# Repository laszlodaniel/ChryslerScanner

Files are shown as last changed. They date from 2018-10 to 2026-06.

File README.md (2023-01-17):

# ChryslerScanner [][License] [][Tindie]

Preview

GUI CCD 01

GUI SCI 01

GUI EngineTools 01

GUI BootstrapTools 01

<!----------------------------------------------------------------------------->

[Badge License]: https://img.shields.io/badge/License-GPLv3-blue.svg?style=for-the-badge
[Badge Tindie]: https://img.shields.io/badge/Buy_On_Tindie-17aeb9?style=for-the-badge&logo=shopify&logoColor=white
[Preview]: https://chryslerccdsci.files.wordpress.com/2022/06/img_20220627_101911_02.jpg
[GUI CCD 01]: https://chryslerccdsci.files.wordpress.com/2023/01/chryslerscanner_gui_ccd_01.png
[GUI SCI 01]: https://chryslerccdsci.files.wordpress.com/2023/01/chryslerscanner_gui_sci_01.png
[GUI EngineTools 01]: https://chryslerccdsci.files.wordpress.com/2023/01/chryslerscanner_gui_enginetools_01.png
[GUI BootstrapTools 01]: https://chryslerccdsci.files.wordpress.com/2023/01/chryslerscanner_gui_bootstraptools_01.png
[Tindie]: https://www.tindie.com/products/27210/
[License]: LICENSE

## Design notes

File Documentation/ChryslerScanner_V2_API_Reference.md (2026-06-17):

# Chrysler Scanner V2 API Reference

> **Last Updated:** June 5, 2026  

## 1. Overview
The Chrysler Scanner firmware acts as a high-speed bridge between modern host applications (Windows, macOS, Android, iOS) and legacy Chrysler automotive networks (CCD, PCI, and SCI). 

Communication with the scanner is purely asynchronous, packet-based, and identical across both USB and Bluetooth LE (BLE) transport layers. The scanner operates in a Master/Slave relationship with the host application: the host issues requests or commands, and the scanner responds. The scanner will also independently push asynchronous events (like incoming automotive bus messages) to the host.

## 2. Transport Layers

### 2.1 USB (Serial Port)
* **Baud Rate:** `250000` bps (Default, configurable via API)
* **Data Bits:** 8
* **Parity:** None
* **Stop Bits:** 1
* **Flow Control:** None

### 2.2 Bluetooth Low Energy (BLE)
The scanner implements the standard **Nordic UART Service (NUS)** to emulate a serial stream over BLE.
* **Service UUID:** `6E400001-B5A3-F393-E0A9-E50E24DCCA9E`
* **RX Characteristic (Host -> Scanner):** `6E400002-B5A3-F393-E0A9-E50E24DCCA9E` (Write / Write Without Response)
* **TX Characteristic (Scanner -> Host):** `6E400003-B5A3-F393-E0A9-E50E24DCCA9E` (Notify)

*Note: BLE MTU size negotiation is supported and highly recommended to maximize throughput.*

---

## 3. Packet Framing Protocol
Every byte of data exchanged between the host and the scanner is wrapped in a strict packet frame. The framing protocol ensures data integrity, synchronizes streams, and explicitly routes payloads.

### 3.1 Packet Structure

| Byte Offset | Field Name | Size | Type | Description |
| :--- | :--- | :--- | :--- | :--- |
| `0` | **Sync** | 1 byte | `uint8` | Always `0x3D` (`=`). Used to synchronize the stream. |
| `1 - 2` | **Length** | 2 bytes | `uint16` | Total length of the Payload + 2 (Big Endian). |
| `3` | **Routing** | 1 byte | `uint8` | Bitmapped field containing Direction, Bus ID, and Command. |
| `4` | **Mode** | 1 byte | `uint8` | Sub-command modifier (varies by Command). |
| `5` to `N-2` | **Payload** | `N` bytes | `uint8[]`| Optional data. Length = `Length field - 2`. |
| `N-1` | **Checksum** | 1 byte | `uint8` | 8-bit additive sum of all preceding bytes. |

**Total Packet Size Calculation:**  
`Total Size = Payload Length + 6 bytes`

### 3.2 The Routing Byte (Byte 3)
The routing byte is a bitmapped flag that determines where the packet came from, what subsystem it targets, and what action to perform.

| Bit 7 (MSB) | Bit 6-4 | Bit 3-0 (LSB) |
| :---: | :---: | :---: |
| **Direction** | **Bus ID** | **Command ID** |

* **Direction Bit:** 
  * `0` = Host to Scanner (Requests)
  * `1` = Scanner to Host (Responses)
* **Bus ID (Bits 6-4):**
  * `0x0` = USB / Internal System
  * `0x1` = CCD Bus
  * `0x2` = SCI Bus (PCM / Engine)
  * `0x3` = SCI Bus (TCM / Transmission)
  * `0x4` = PCI Bus
* **Command ID (Bits 3-0):**
  * `0x0` = Reset
  * `0x1` = Handshake
  * `0x2` = Status
  * `0x3` = Settings
  * `0x4` = Request
  * `0x5` = Response
  * `0x6` = Message TX (Send to Car)
  * `0x7` = Message RX (Received from Car)
  * `0xC` = File Operations
  * `0xD` = Bootloader / ECU Flashing
  * `0xE` = Debug / Emulator
  * `0xF` = Error

### 3.3 Checksum Calculation
The checksum is a simple 8-bit unsigned rollover sum of all bytes in the packet *excluding* the checksum byte itself.

**C# / C++ Example:**
```csharp
public byte CalculateChecksum(byte[] buffer, int lengthWithoutChecksum)
{
    byte checksum = 0;
    for (int i = 0; i < lengthWithoutChecksum; i++)
    {
        checksum += buffer[i]; // Rollover is intentional
    }
    return checksum;
}
```

---

## 4. Packet Construction Example

**Scenario:** Host wants to request the scanner's Hardware/Firmware Info.
* `Sync`: `0x3D`
* `Length`: `0x0002` (0 Payload bytes + 2)
* `Routing`: `0x04` (Direction=0, Bus=USB[0], Cmd=Request[4])
* `Mode`: `0x01` (Req_HwFw_Info)
* `Payload`: [None]

**Raw Host TX:** `3D 00 02 04 01 44` *(0x44 is the sum of 3D+00+02+04+01)*

**Scanner Response:**
* `Sync`: `0x3D`
* `Length`: `0x0019` (23 Payload bytes + 2)
* `Routing`: `0x85` (Direction=1, Bus=USB[0], Cmd=Response[5])
* `Mode`: `0x01` (Res_HwFw_Info)
* `Payload`: `[23 bytes of Hardware/Firmware Data]`

---

## 5. Global Error Responses
If the host sends an invalid packet or the scanner encounters an internal error, it will respond with an **Error Packet**.

**Routing Byte:** `0x8F` (Scanner to Host, USB Bus, Error Command)
**Payload:** Usually a single `0xFF` byte, though it can be ignored.
**Mode Byte (The Error Code):**
* `0x00` = OK (Acknowledge)
* `0x01` = Length Invalid Value
* `0x02` = Invalid Command (Command ID not recognized)
* `0x03` = Invalid Mode (Mode/Sub-command not recognized)
* `0x04` = Invalid Payload Values
* `0x05` = Checksum Invalid
* `0x06` = Packet Timeout (RX stream stalled)
* `0x07` = Buffer Overflow
* `0x08` = Invalid Bus
* `0xFE` = Internal Execution Error
* `0xFF` = Fatal Error

*Example of a standard "OK" ACK from the scanner (Length=3, Payload=[0x00]):*  
`3D 00 03 8F 00 00 CF`

---

# 6. Core System Commands

These commands handle the fundamental lifecycle and identification of the scanner.

### 6.1 Reset Scanner (`Command ID: 0x00`)
Reboots the ESP32 microcontroller or notifies the host that a reboot has occurred.

*   **Host Request Mode:** `0x00` (`rm_init`)
    *   **Payload:** 1 byte (Reset reason requested by host, user-defined)
*   **Scanner Response Mode:** `0x01` (`rm_done`)
    *   **Payload:** 1 byte (Actual hardware reset reason, via `esp_reset_reason()`)
    *   *Note: The scanner broadcasts this automatically upon startup.*

### 6.2 Handshake (`Command ID: 0x01`)
Used to identify the device and verify communication channels are active.

*   **Host Request Mode:** `0x00` (`hm_none`)
    *   **Payload:** None
*   **Scanner Response Mode:** `0x00`
    *   **Payload:** 15 bytes (ASCII String: `CHRYSLERSCANNER`)

### 6.3 Status (`Command ID: 0x02`)
Retrieves a comprehensive real-time snapshot of the scanner's internal state, memory, voltages, and bus statistics.

*   **Host Request Mode:** `0x00` (`sm_none`)
    *   **Payload:** None
*   **Scanner Response Mode:** `0x00`
    *   **Payload:** 45 bytes (All multi-byte integers are **Big-Endian**)

| Byte Offset | Type | Description |
| :--- | :--- | :--- |
| `0 - 3` | `uint32` | Device Uptime in milliseconds |
| `4 - 7` | `uint32` | RAM Usage (Total Heap - Free Heap) in bytes |
| `8 - 9` | `uint16` | Battery Voltage (mV) |
| `10 - 11` | `uint16` | Bootstrap Voltage / VBB (mV) |
| `12 - 13` | `uint16` | Programming Voltage / VPP (mV) |
| `14` | `uint8` | Current CCD-Bus Settings Byte |
| `15 - 18` | `uint32` | CCD-Bus RX Packet Count |
| `19 - 22` | `uint32` | CCD-Bus TX Packet Count |
| `23` | `uint8` | Current PCI-Bus Settings Byte |
| `24 - 27` | `uint32` | PCI-Bus RX Packet Count |
| `28 - 31` | `uint32` | PCI-Bus TX Packet Count |
| `32` | `uint8` | Current SCI-Bus Settings Byte |
| `33 - 36` | `uint32` | SCI-Bus RX Packet Count |
| `37 - 40` | `uint32` | SCI-Bus TX Packet Count |
| `41 - 42` | `uint16` | LED Heartbeat Interval (ms) |
| `43 - 44` | `uint16` | LED Blink Duration (ms) |

---

# 7. Device Settings (`Command ID: 0x03`)
Settings commands configure hardware peripherals. The scanner automatically saves these parameters to Non-Volatile Storage (NVS) and acknowledges by echoing the packet back (`Direction` bit set to `1`).

### 7.1 Set LED Mode (`Mode: 0x01`)
Configures the device's status LEDs.
*   **Payload:** 4 bytes
    *   Bytes 0-1: Heartbeat Interval (ms) (`0` = disable heartbeat)
    *   Bytes 2-3: Blink Duration (ms) (`0` = completely disable LEDs)

### 7.2 Set CCD-Bus Configuration (`Mode: 0x02`)
*   **Payload:** 1 byte (Bit 7: `1` = Enable Bus, `0` = Disable Bus)

### 7.3 Set PCI-Bus Configuration (`Mode: 0x06`)
*   **Payload:** 1 byte (Bit 7: `1` = Enable Bus, `0` = Disable Bus)

### 7.4 Set SCI-Bus Configuration (`Mode: 0x03`)
SCI setup requires strict multiplexing of the `AW9523` port expander and UART logic levels.
*   **Payload:** 1 byte (Bitmapped)

| Bit(s) | Function | Description |
| :---: | :--- | :--- |
| `7` | **Enable** | `1` = Enable transceiver, `0` = Disable |
| `6` | **Nibble Swap** | `1` = Swap 4-bit nibbles in received/transmitted bytes |
| `5` | **Module Target** | `0` = PCM (Engine), `1` = TCM (Transmission) |
| `4` | **NGC Mode** | `1` = Next Generation Controller, `0` = Legacy (SBEC/JTEC/EATX) |
| `3` | **Logic Polarity** | `1` = Inverted / OBD1, `0` = Normal / OBD2 |
| `2` | **OBD Config** | Pin routing switch. `0` = Config A, `1` = Config B |
| `1 - 0` | **Baudrate** | `0` = 976, `1` = 7812, `2` = 62500, `3` = 125000 bps |

### 7.5 Apply SCI VXX Strobe Voltage (`Mode: 0x07`)
Activates hardware level-shifters to apply high voltage directly to the active SCI-TX pin. Crucial for flashing or unlocking bootstrap modes.
*   **Payload:** 2 bytes (`uint16`, Big-Endian) in millivolts.
    *   `0x0000` (0) = `VXX_NONE` (Off)
    *   `0x2EE0` (12000) = `VBB` (Bootstrap Voltage)
    *   `0x4E20` (20000) = `VPP` (Programming Voltage)

### 7.6 Set USB UART Baudrate (`Mode: 0x08`)
Changes the baud rate of the primary USB Serial connection.
*   **Payload:** 4 bytes (`uint32`, Big-Endian). *Default is 250,000.*

---

# 8. System Requests (`Command ID: 0x04`)
Requests prompt the scanner to return specific diagnostic information. The scanner responds with `Command ID: 0x05`.

| Request Mode (`0x04`) | Response Mode (`0x05`) | Payload Description (Response) |
| :--- | :--- | :--- |
| `0x01` (HW/FW Info) | `0x01` | **23 Bytes:** HW Ver (4 bytes, nibble-split), FW Major, Minor, Build, Rev (4 bytes), Chip Model (1 byte), Chip Rev (2 bytes), Cores (1 byte), Features (4 bytes), Flash Size in MB (1 byte), Bluetooth MAC Address (6 bytes). |
| `0x02` (Timestamp) | `0x02` | **4 Bytes:** `uint32` Milliseconds since boot. |
| `0x03` (Battery Volts) | `0x03` | **2 Bytes:** `uint16` Voltage in mV. |
| `0x06` (VBB Volts) | `0x06` | **2 Bytes:** `uint16` 12V Bootstrap output in mV. |
| `0x07` (VPP Volts) | `0x07` | **2 Bytes:** `uint16` 20V Programming output in mV. |
| `0x08` (All Voltages) | `0x08` | **6 Bytes:** Batt, VBB, VPP (`uint16` x 3). |

---

# 9. Debug & OTA Updates (`Command ID: 0x0E`)
These sub-commands interact with the ESP32's deeper system functions, including Over-The-Air firmware updates and the internal hardware SCI emulator.

### 9.1 SCI Emulator Commands
The scanner can physically simulate a Chrysler PCM/TCM on the SCI bus for software testing without a real vehicle.
*   **Enable/Disable Emulator (`Mode: 0x0B`):** 
    *   Payload: `0x01` (Enable), `0x00` (Disable)
*   **Set Emulator OBD1 Mode (`Mode: 0x0D`):**
    *   Payload: `0x01` (OBD1 Logic), `0x00` (OBD2 Logic)
*   **Set Emulator ECM Mode (`Mode: 0x0E`):**
    *   Payload: `0x01` (Cummins Diesel Engine Controller), `0x00` (Normal Engine Controller)
*   **Upload Emulator Data Blob (`Mode: 0x0C`):**
    *   Payload: Up to 1024 bytes. This binary blob defines the simulated diagnostic fault codes, ROM IDs, and sensor responses. The scanner stores this blob in NVS. Blob format is not public yet.

### 9.2 Over-The-Air (OTA) Firmware Updates
Allows 3rd-party apps to flash new ESP32 firmware updates directly to the scanner over USB or BLE.

1.  **Start OTA (`Mode: 0x15`):** Payload: None. Opens the inactive OTA partition.
2.  **Set Hash (`Mode: 0x17`):** Payload: 32 bytes (SHA-256 Hash of the `.bin` file). *Highly recommended to verify integrity.*
3.  **Write Chunk (`Mode: 0x18`):** Payload: Variable length data chunk. Send sequentially until the `.bin` file is fully transferred.
4.  **Finalize OTA (`Mode: 0x19`):** Payload: None. Verifies the SHA-256 hash against the written partition, sets the boot flag, and automatically reboots the scanner.
5.  **Abort OTA (`Mode: 0x16`):** Payload: None. Cancels an active OTA and cleans up.
6.  **Revert Firmware (`Mode: 0x1A`):** Payload: None. Rolls the scanner back to the previously installed firmware version and reboots.

### 9.3 System Debug
*   **Get Task Stack Statistics (`Mode: 0x20`):** Payload: None. Prints FreeRTOS High-Water Marks to the debug UART to check for memory leaks.
*   **Set BLE MTU Size (`Mode: 0x30`):** 
    *   Payload: 2 bytes (`uint16` Big-Endian). Requests a larger Maximum Transmission Unit for BLE before connection to maximize Bluetooth bandwidth.

---

# 10. Automotive Bus Messaging

The scanner allows raw data injection and extraction from the vehicle's CCD, PCI, and SCI networks. 

*   **Host to Scanner (Transmit):** Command ID `0x06` (`cmd_msg_tx`)
*   **Scanner to Host (Receive):** Command ID `0x07` (`cmd_msg_rx`)

### 10.1 Receiving Messages from the Vehicle
When the scanner receives a valid message on an active bus, it wraps it in an `0x07` packet and pushes it asynchronously to the host.

**Response Mode Byte:**
*   `0x01`: CCD, PCI, or SCI Low-Speed message.
*   `0x02`: SCI High-Speed message (Multiplexed/Streamed/Bootstrap).

**Payload Structure (RX):**
| Byte Offset | Type | Description |
| :--- | :--- | :--- |
| `0 - 3` | `uint32` | **Timestamp:** Milliseconds since the scanner booted (Big-Endian). Extremely useful for Host-side charting/logging. |
| `4 - N` | `uint8[]` | **Raw Bus Message:** The actual bytes captured from the vehicle network (including checksums/CRCs if applicable). |

### 10.2 Transmitting Messages to the Vehicle
When transmitting, the host specifies *how* the scanner should push the data using the **Mode** byte.

*   `0x01` (**Stop**): Stops any active repeating transmission loops. (Payload: None)
*   `0x02` (**Single**): Transmits the payload once.
*   `0x03` (**List**): Transmits a sequence of different messages sequentially.
*   `0x04` (**Repeat**): Transmits a message (or sequence) infinitely at a strict hardware-timed interval.
*   `0x81` (**Single + VBB**): *[SCI Bus Only]* Transmits the payload once, then immediately applies 12V Bootstrap Voltage to the SCI-TX pin (used for waking up PCMs in Bootstrap mode).
*   `0x82` (**Single + VPP**): *[SCI Bus Only]* Transmits the payload once, then immediately applies 20V Programming Voltage to the SCI-TX pin (used for unlocking Flash memory).

**Payload Structure (Single TX `0x02`, `0x81`, `0x82`):**
Simply append the raw bytes. 
*Note: For CCD, the scanner hardware automatically calculates and appends the 8-bit checksum. For PCI, it calculates and appends the J1850 CRC. For SCI (Legacy), the host must provide the exact bytes. For SCI (NGC), the scanner appends the checksum automatically.*

**Payload Structure (Repeat / List TX `0x03`, `0x04`):**
| Byte Offset | Type | Description |
| :--- | :--- | :--- |
| `0 - 1` | `uint16` | **Interval:** Delay in milliseconds between transmissions. |
| `2` | `uint8` | **Length (L1):** Length of the first message. |
| `3 - (3+L1-1)` | `uint8[]` | **Message 1 Data** |
| `3+L1` | `uint8` | **Length (L2):** Length of the second message (optional). |
| `...` | `...` | ... repeats up to 1024 bytes of buffer space. |

---

# 11. Internal Storage (LittleFS)
The scanner uses an internal Flash partition (LittleFS) to store firmware for backup dumps or files intended for writing. Command ID: `0x0C`.

| Mode (`0x0C`) | Action | Host Payload | Scanner Response Payload |
| :--- | :--- | :--- | :--- |
| `0x01` | **Storage Info** | None | `Total Bytes` (uint32), `Used Bytes` (uint32), followed by a concatenated list of files (see 11.1). |
| `0x02` | **File Info** | Null-terminated string (Filename) | `Filename` (\0), `Exists` (uint8, 1=true), `Size` (uint32). |
| `0x03` | **Upload File** | `Filename` (\0), followed by raw byte chunk. | Standard ACK (`0x00`) or Error (`0xFF`). |
| `0x04` | **Download File** | `Filename` (\0), `Block Size` (uint16). | Scanner starts pushing chunks to host via Mode `0x04`. |
| `0x05` | **Rename File** | `Old Name` (\0), `New Name` (\0), `Overwrite` (uint8 boolean). | Standard ACK or Error. |
| `0x06` | **Delete File** | Null-terminated string (Filename). | Standard ACK or Error. |
| `0x07` | **Format** | None. (Wipes the entire LittleFS partition). | Standard ACK or Error. |
| `0x08` | **Cancel DL** | None. Stops an active `0x04` download stream. | Standard ACK. |
| `0x10` | **Read Chunk** | `Filename` (\0), `Offset` (uint32), `Length` (uint32). | Scanner returns the exact byte chunk requested. |

### 11.1 Storage Info File List Format
When requesting Storage Info (`0x01`), the file list appended to the payload is structured as follows:
`[Total Files (uint8)] [Record Length (uint8)] [Filename (\0)] [Size (uint32)] ...`
*Example: `01 12 74 65 73 74 2E 62 69 6E 00 00 00 00 80` -> 1 File, 18 bytes record length, "test.bin", 128 bytes size.*

---

# 12. ECU Bootloader & Flashing (Autoboot)
Flashing vintage engine controllers requires microsecond-perfect timing to inject bootstrap code into the target MCU's RAM. Because USB/BLE latency is unpredictable, the **ESP32 handles the entire state machine natively**. The Host app simply configures the job and monitors progress.

Command ID: `0x0D` (`cmd_boot`)

### 12.1 Target ECU Loaders (Byte 0)
*   `0x01` = SBEC2
*   `0x02` = SBEC3 / SBEC3+
*   `0x03` = SBEC3A / SBEC3A+ / SBEC3B
*   `0x04` = EATX3 / EATX3A (Transmission)
*   `0x05` = EATX3B (Transmission)
*   `0x06` = EATX4 (Transmission)
*   `0x07` = JTEC
*   `0x08` = JTEC+

### 12.2 Operation Modes
The Host sends an `0x0D` packet with one of the following **Modes**:

#### Automated State Machines
*   `0x01` (`bm_flash_write`): Full Flash Write cycle (Unlock, Erase, Write, Verify).
*   `0x02` (`bm_flash_read`): Full Flash Backup cycle (Unlock, Read to LittleFS).
*   `0x03` (`bm_eeprom_write`): EEPROM Write cycle.
*   `0x04` (`bm_eeprom_read`): EEPROM Read cycle.
*   `0x0A` (`bm_read_68hc11`): Read Co-Processor memory.

**Host Payload for Automated Modes:**
| Byte | Description |
| :--- | :--- |
| `0` | **Loader ID** (e.g., `0x01` for SBEC2) |
| `1` | **Flags (Bitmapped)**<br>Bit 0: Backup original to LittleFS before writing (`1` = yes)<br>Bit 1: Is 64K Chip? (`1` = 64K, `0` = 32K, SBEC2 only)<br>Bit 2: Is Jeep variant? (`1` = Jeep, SBEC2 only)<br>Bit 3: Deep Erase (`1` = Force full wipe) |
| `2 - N` | **Null-Terminated String:** Filename in LittleFS to Read from. |

#### State Machine Control
*   `0x09` (`bm_cancellation_request`): Safely aborts an active Autoboot sequence. (Payload: None)
*   `0x0B` (`bm_boot_next_task_request`): Acknowledges a host prompt. *(Note: SBEC2 controllers must be power-cycled during the write sequence. The ESP32 will pause the state machine and wait for the Host to send `0x0B` after the user cycles the ignition key).*

### 12.3 Status Notifications
While the Autoboot sequence runs, the scanner pushes continuous status updates to the Host (Direction = `1`, Command = `0x0D`). 

The **Payload** of these status updates contains a 1-byte Status Code, optionally followed by data.

**Success / Progression Codes:**
*   `0x00`: Job Complete Successfully.
*   `128`: Verifying Voltages...
*   `129`: Voltages OK.
*   `132`: Part Number Extracted. (Payload: ASCII String of Part Number).
*   `133`: Backup Created. (Payload: ASCII String of generated backup filename).
*   `136`: Flash IDs Extracted. (Payload: 2 bytes `[Manufacturer ID] [Chip ID]`).
*   `142`: Flash Erase Result. (Payload: 1 byte response from worker, `0x22` is success).
*   `168`: Re-uploading Bootloader (Prompting user for Ignition Cycle).

**Error Codes (Causes immediate sequence halt):**
*   `01`: Flash File Missing in LittleFS.
*   `02`: Flash File Size Mismatch.
*   `03`: Storage Full (Cannot create backup).
*   `05`: Battery Voltage Low (< 11.5V).
*   `06`: Bootstrap Voltage VBB Low (< 11.5V).
*   `07`: Programming Voltage VPP Low (< 19.0V).
*   `12`: Flash Checksum Mismatch (Write verification failed).
*   `18`: Upload Worker Timeout.
*   `19`: Start Worker Timeout.
*   `22`: Task Cancelled by Host.

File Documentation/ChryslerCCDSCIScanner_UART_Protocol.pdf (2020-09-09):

Chrysler CCD/SCI Scanner V1.4X | UART Protocol

## Chrysler CCD/SCI Scanner UART Protocol

V1.4X

Last update: 2020.09.09

## 1. Frame format

Start of frame | Frame length | Frame description | Data | End of frame
SYNC | LENGTH HB | LENGTH LB | DATA CODE | SUB-DATA CODE | PAYLOAD | CHECKSUM
3D | 00 | 06 | 05 | 02 | 00 DA A9 0D | 9D

Table 1. Frame format example (hex numbers implied).

SYNC byte: fixed value at the beginning of every frame (3D).

LENGTH bytes: number of bytes following (not including these two) until the CHECKSUM byte is reached. Maximum frame length is limited to 1024 bytes.
Size: 2 bytes.

DATA CODE byte: describes the source, target and command. Size: 1 byte.

SUB-DATA CODE byte: command extension if the command alone is not enough to describe the purpose of the frame. Size: 1 byte

PAYLOAD byte(s): optional. Arbitrary data can be stored here. Size: limited to a maximum of 1024-6=1018 bytes.

CHECKSUM byte: all bytes, except SYNC, summed up, lower byte of the result is placed here for error detection. Size: 1 byte.

Frame transmission and reception is realized via +5V logic serial communication with non-return-to-zero (NRZ) encoding at 250000 baudrate either trough the USB or FTDI connector.

## 2. Frame bytes in detail

### 2.1 DATA CODE byte description

DATA CODE byte
Source | Target | Command
bit 7 | bit 6 | bit 5 | bit 4 | bit 3 | bit 2 | bit 1 | bit 0
0 | 0 | 1 | 0 | 0 | 1 | 1 | 0
Table 2. DATA CODE byte description.

Bit 7:6 – Source of the frame: 00b: USB
01b: CCD
10b: PCM
11b: TCM

Bit 5:4 – Target of the frame: 00b: USB
01b: CCD
10b: PCM
11b: TCM

USB: the scanner/laptop itself.
CCD: all modules on CCD-bus.
PCM: engine controller on SCI-bus.
TCM: transmission controller on a separate SCI-bus. This channel is currently unused. TCMs mainly communicate on the CCD-bus and can be reached there for diagnostics purposes.

Bit 3:0 – Command
0000b (00): Reset
0001b (01): Handshake
0010b (02): Status
0011b (03): Settings
0100b (04): Request
0101b (05): Response
0110b (06): Message TX
0111b (07): Message RX
1000b-1101b (08-0D): reserved
1110b (0E): Debug
1111b (0F): OK/Error

### 2.2 SUB-DATA CODE byte description

Individual bits have no special meaning. Different commands have different SUB-DATA CODE bytes associated with them. When not used it always reads 00, otherwise this value extends the meaning of the DATA CODE byte.

## 3. Frame examples

### 3.1 Reset (command: 00)

Applicable SUB-DATA CODE bytes (modes): 00: initiate scanner reset.
01: scanner reset done.
02-FF: reserved.
SYNC | LENGTH HB | LENGTH LB | DATA CODE | SUB-DATA CODE | PAYLOAD | CHECKSUM
3D | 00 | 02 | 00 | 00 | | 02

Table 3. Reset scanner request frame.

SYNC | LENGTH HB | LENGTH LB | DATA CODE | SUB-DATA CODE | PAYLOAD | CHECKSUM
3D | 00 | 03 | 00 | 00 | 00 | 03

Table 4. Scanner is being reset frame.

SYNC | LENGTH HB | LENGTH LB | DATA CODE | SUB-DATA CODE | PAYLOAD | CHECKSUM
3D | 00 | 03 | 00 | 01 | 00 | 04

Table 5. Scanner reset complete frame.

Note that the scanner never sends a communication packet without payload but accepts them without one. In a response made by the scanner at least a single 00 byte is included and it generally means success.

### 3.2 Handshake (command: 01)

Applicable SUB-DATA CODE bytes (modes):
00: request handshake only.
01: request handshake, hardware/firmware information and scanner status. 02-FF: reserved.
SYNC | LENGTH HB | LENGTH LB | DATA CODE | SUB-DATA CODE | PAYLOAD | CHECKSUM
3D | 00 | 02 | 01 | 00 | | 03

Table 6. Handshake request frame.

SYNC | LENGTH HB | LENGTH LB | DATA CODE | SUB-DATA CODE | PAYLOAD | CHECKSUM
3D | 00 | 02 | 01 | 01 | | 04

Table 7. Handshake request frame with additional information.

SYNC | LENGTH HB | LENGTH LB | DATA CODE | SUB-DATA CODE | PAYLOAD | CHECKSUM
3D | 00 | 17 | 01 | 00 | 43 48 52 59 53 4C 45 52 43 43 44 53 43 49 53 43 41 4E 4E 45 52 | 37

Table 8. Handshake response frame.

PAYLOAD contains an ASCII encoded text:
43 48 52 59 53 4C 45 52 43 43 44 53 43 49 53 43 41 4E 4E 45 52 = CHRYSLERCCDSCISCANNER

A third party software should look for a response like this when searching for the scanner among many serial devices.

Another 2 separate frames are sent by the scanner when additional information is requested: 1 hardware/firmware version and 1 status frame.

### 3.3 Status (command: 02)

No sub-data code byte/mode is applicable here, reads always 00.

SYNC | LENGTH HB | LENGTH LB | DATA CODE | SUB-DATA CODE | PAYLOAD | CHECKSUM
3D | 00 | 02 | 02 | 00 | | 04

Table 9. Status request frame.

SYNC | LENGTH HB | LENGTH LB | DATA CODE | SUB-DATA CODE | PAYLOAD | CHECKSUM
3D | 00 | 2E | 02 | 00 | 1E 98 01 01 31 31 00 1E AC AE 0B B2 00 00 00 51 00 00 00 00 00 00 00 00 91 00 00 00 0C 00 00 00 0C 01 27 14 04 14 01 02 13 88 00 32 | 9D

Table 10. Status response frame.

PAYLOAD offset:
00-02: AVR signature (1E 98 01 for ATmega2560).
03: | external EEPROM present (00: false, 01: true).
04: | external EEPROM checksum.
05: | external EEPROM calculated checksum.
06-09: current timestamp in milliseconds.
0A-0B: RAM usage out of 8192 bytes.
0C: connected to vehicle (00: false, 01: true).
0D-0E: measured vehicle battery voltage (multiplied by 100).
0F: | CCD-bus status byte:
| Bit 7:6 – bus id bits, reads 01b for CCD-bus.
| Bit 5: – change settings bit, reads always 0b (0b: keep, 1b: change).
| Bit 4: – state bit (0b: disabled, 1b: enabled).
| Bit 3: – logic bit, reads always 0b (0b: non-inverted, 1b: inverted).
| Bit 2: – termination and bias (TB) bit (0b: disabled, 1b: enabled).
| Bit 1:0 – baudrate bits (00b: 976.5, 01b: 7812.5, 10b: 62500, 11b:
| 125000), reads always 01b as the only known communication
| speed for CCD-bus.
10-13: number of CCD-bus messages received. 14-17: number of CCD-bus messages sent.
18: | SCI-bus (PCM) status byte:
| Bit 7:6 – bus id bits, reads 10b for the PCM.
| Bit 5: – change settings bit (0b: keep settings, 1b: change settings).
| Bit 4: – state bit (0b: disabled, 1b: enabled).
| Bit 3: – logic bit (0b: non-inverted, 1b: inverted).
| Bit 2: – OBD configuration bit (0b: A, 1b: B).
| Bit 1:0 – baudrate bits (00b: 976.5, 01b: 7812.5, 10b: 62500, 11b:
| 125000), 7812.5 and 62500 baud are most commonly used.
19-1C: number of SCI-bus (PCM) messages received. 1D-20: number of SCI-bus (PCM) messages sent.
21: | LCD state (00: disabled, 01: enabled).
22: | LCD I2C address.
23: | LCD width in characters.
24: | LCD height in characters.
25: | LCD refresh rate in Hz.
26: | LCD units (00: imperial, 01: metric).
27: | LCD data source (01: CCD-bus, 02: SCI-bus PCM, 03: SCI-bus TCM).
28-29: LED heartbeat interval in milliseconds.
2A-2B: LED blink duration in milliseconds.

### 3.4 Settings (command: 03)

Applicable SUB-DATA CODE bytes (modes): 01: heartbeat / LED behavior.
02: set CCD-bus.
03: set SCI-bus.
04: set repeat behavior.
05: set LCD.
00,06-FF: reserved.

### 3.4.1 Heartbeat / LED behavior mode

SYNC | LENGTH HB | LENGTH LB | DATA CODE | SUB-DATA CODE | PAYLOAD | CHECKSUM
3D | 00 | 06 | 03 | 01 | 13 88 00 32 | D7

Table 11. Change heartbeat / LED behavior setting frame.

PAYLOAD offset:
00-01: heartbeat interval in milliseconds, 5000 ms = 13 88. 02-03: blink duration for all LEDs in milliseconds, 50 ms = 00 32.
SYNC | LENGTH HB | LENGTH LB | DATA CODE | SUB-DATA CODE | PAYLOAD | CHECKSUM
3D | 00 | 07 | 03 | 01 | 00 13 88 00 32 | D8

Table 12. Heartbeat / LED behavior setting response frame.

PAYLOAD offset:
00: setting state (00: ok, FF: error). 01-02: heartbeat interval in milliseconds. 03-04: LED blink duration in milliseconds.

### 3.4.2 Set CCD-bus mode

SYNC | LENGTH HB | LENGTH LB | DATA CODE | SUB-DATA CODE | PAYLOAD | CHECKSUM
3D | 00 | 04 | 03 | 02 | 01 00 | 0A

Table 13. Change CCD-bus setting frame.

PAYLOAD offset:
00: CCD-bus state (00: disabled, 01: enabled).
01: internal CCD-bus termination and bias state (00: disabled,
01: enabled). This feature is available for V1.44+ hardware versions only.
SYNC | LENGTH HB | LENGTH LB | DATA CODE | SUB-DATA CODE | PAYLOAD | CHECKSUM
3D | 00 | 05 | 03 | 02 | 00 01 00 | 0B

Table 14. CCD-bus setting response frame.

PAYLOAD offset:
00: setting state (00: ok, FF: error).
01: CCD-bus state.
02: internal CCD-bus termination and bias state.

### 3.4.3 Set SCI-bus mode

SYNC | LENGTH HB | LENGTH LB | DATA CODE | SUB-DATA CODE | PAYLOAD | CHECKSUM
3D | 00 | 03 | 03 | 03 | B1 | BA

Table 15. Change SCI-bus setting frame.

PAYLOAD offset:
00: SCI-bus status:
Bit 7:6 – bus id bits, reads 10b for the PCM (11b for TCM).
Bit 5: – change settings bit (0b: keep settings, 1b: change settings). Bit 4: – state bit (0b: disabled, 1b: enabled).
Bit 3: – logic bit (0b: non-inverted, 1b: inverted).
Bit 2: – OBD configuration bit (0b: A, 1b: B).
Bit 1:0 – baudrate bits (00b: 976.5, 01b: 7812.5, 10b: 62500, 11b: 125000)

Example: B1 = 10110001b
10b: PCM
1b: change settings
1b: enabled state
0b: non-inverted logic
0b: A-configuration
01b: 7812.5 baudrate

The 5th change settings bit must always be set, otherwise the scanner ignores the request.

SYNC | LENGTH HB | LENGTH LB | DATA CODE | SUB-DATA CODE | PAYLOAD | CHECKSUM
3D | 00 | 04 | 03 | 03 | 00 91 | 9B

Table 16. SCI-bus setting response frame.

PAYLOAD offset:
00: setting state (00: ok, FF: error). 01: SCI-bus state.

Example: 91 = 10010001b
10b: PCM
0b: keep settings
1b: enabled state
0b: non-inverted logic
0b: A-configuration
01b: 7812.5 baudrate

The 5th change settings bit is necessarily cleared if it comes as a response.

### 3.4.4 Set repeat behavior mode

SYNC | LENGTH HB | LENGTH LB | DATA CODE | SUB-DATA CODE | PAYLOAD | CHECKSUM
3D | 00 | 07 | 03 | 04 | 01 00 64 00 02 | 75

Table 17. Change repeat behavior setting frame.

PAYLOAD offset:
00: target bus (01: CCD-bus, 02: SCI-bus PCM, 03: SCI-bus TCM).
01-02: message repeat interval in milliseconds, 100 ms = 00 64.
03-04: message increment for every repeat, 2 = 00 02.

When message repeating is enabled the scanner uses the interval set here for message timing. Message incrementing is applicable to a specific B2-request message only.

SYNC | LENGTH HB | LENGTH LB | DATA CODE | SUB-DATA CODE | PAYLOAD | CHECKSUM
3D | 00 | 08 | 03 | 04 | 00 01 00 64 00 02 | 76

Table 18. Repeat behavior setting response frame.

PAYLOAD offset:
00: setting state (00: ok, FF: error).
01: target bus.
02-03: message repeat interval in milliseconds. 04-05: message increment for every repeat.

### 3.4.5 Set LCD mode

SYNC | LENGTH HB | LENGTH LB | DATA CODE | SUB-DATA CODE | PAYLOAD | CHECKSUM
3D | 00 | 09 | 03 | 05 | 01 27 14 04 14 01 02 | 68

Table 19. Change LCD setting frame.

PAYLOAD offset:
00: state (00: disabled, 01: enabled). 01: I2C address, 27 (hex).
02: character width, 14: 20 characters. 03: character height, 04: 4 characters.
04: refresh rate in Hz, 14: 20 Hz.
05: units (00: imperial, 01: metric).
06: data source (01: CCD-bus, 02: SCI-bus PCM, 03: SCI-bus TCM).
SYNC | LENGTH HB | LENGTH LB | DATA CODE | SUB-DATA CODE | PAYLOAD | CHECKSUM
3D | 00 | 0A | 03 | 05 | 00 01 27 14 04 14 01 02 | 69

Table 20. LCD setting response frame.

PAYLOAD offset:
00: setting state (00: ok, FF: error).
01-07: current LCD settings, refer to Table 19’s PAYLOAD offset.

LCD settings are saved to the external EEPROM.

### 3.5 Request/Response (command: 04/05)

Applicable SUB-DATA CODE bytes (modes):
01: hardware/firmware information.
02: timestamp.
03: battery voltage.
04: external EEPROM checksum.
05: CCD-bus voltages.
00,06-FF: reserved.

### 3.5.1 Hardware/Firmware information request mode

SYNC | LENGTH HB | LENGTH LB | DATA CODE | SUB-DATA CODE | PAYLOAD | CHECKSUM
3D | 00 | 02 | 04 | 01 | | 07

Table 21. Hardware/Firmware information request frame.

SYNC | LENGTH HB | LENGTH LB | DATA CODE | SUB-DATA CODE | PAYLOAD | CHECKSUM
3D | 00 | 1C | 05 | 01 | 00 8C 00 00 00 00 5B 7B EA 33 00 00 00 00 5C 02 56 AF 00 01 00 00 5F 19 B9 2A | 60

Table 22. Hardware/Firmware information response frame.

PAYLOAD offset:
00-01: hardware version, 00 8C = 140 -> v1.40. 02-09: hardware date, 00 00 00 00 5B 7B EA 33: 64-bit UNIX time (2018.08.21 12:32:19). 0A-11: assembly date, 00 00 00 00 5C 02 56 AF: 64-bit UNIX time (2018.12.01 10:38:55).
12-09: firmware version/date:
00 01 00 00: major minor patch (build) -> v0.1.0(.0),
5F 19 B9 2A: 32-bit UNIX time (2020.07.23 18:22:02).

### 3.5.2 Timestamp request mode

SYNC | LENGTH HB | LENGTH LB | DATA CODE | SUB-DATA CODE | PAYLOAD | CHECKSUM
3D | 00 | 02 | 04 | 02 | | 08

Table 23. Timestamp request frame.

SYNC | LENGTH HB | LENGTH LB | DATA CODE | SUB-DATA CODE | PAYLOAD | CHECKSUM
3D | 00 | 06 | 05 | 02 | 01 F2 03 23 | 26

Table 24. Timestamp response frame.

PAYLOAD offset:
00-03: milliseconds elapsed since last reset: 01 F2 03 23 = 32637731 ms = 09:03:57.731 (HH:mm:ss.fff).

### 3.5.3 Battery voltage request mode

SYNC | LENGTH HB | LENGTH LB | DATA CODE | SUB-DATA CODE | PAYLOAD | CHECKSUM
3D | 00 | 02 | 04 | 03 | | 09

Table 25. Battery voltage request frame.

SYNC | LENGTH HB | LENGTH LB | DATA CODE | SUB-DATA CODE | PAYLOAD | CHECKSUM
3D | 00 | 06 | 05 | 03 | 04 E0 | F2

Table 26. Battery voltage response frame.

PAYLOAD offset:
00-01: battery voltage multiplied by 100, 04 E0 = 1248 = 12.48 V.

### 3.5.4 External EEPROM checksum request mode

SYNC | LENGTH HB | LENGTH LB | DATA CODE | SUB-DATA CODE | PAYLOAD | CHECKSUM
3D | 00 | 02 | 04 | 04 | | 0A

Table 27. External EEPROM checksum request frame.

SYNC | LENGTH HB | LENGTH LB | DATA CODE | SUB-DATA CODE | PAYLOAD | CHECKSUM
3D | 00 | 05 | 05 | 04 | 01 AE AE | 6B

Table 28. External EEPROM checksum response frame.

PAYLOAD offset:
00: checksum state (00: error, 01: ok). 01: stored checksum, AE.
02: calculated checksum, AE.

### 3.5.5 CCD-bus voltages request mode

SYNC | LENGTH HB | LENGTH LB | DATA CODE | SUB-DATA CODE | PAYLOAD | CHECKSUM
3D | 00 | 02 | 04 | 05 | | 0B

Table 29. CCD-bus voltages request frame.

SYNC | LENGTH HB | LENGTH LB | DATA CODE | SUB-DATA CODE | PAYLOAD | CHECKSUM
3D | 00 | 06 | 05 | 05 | 00 F8 00 FC | 04

Table 30. CCD-bus voltages response frame.

PAYLOAD offset:
00-01: CCD+ wire voltage multiplied by 100, 00 F8 = 248 = 2.48 V.
02-03: CCD- wire voltage multiplied by 100, 00 FC = 252 = 2.52 V.

CCD-bus wire voltage measuring is available for V1.44+ hardware versions only.

### 3.6 Message TX/RX (command: 06/07)

Applicable SUB-DATA CODE bytes (modes):
01: stop message transmission.
02: send a single message once.
03: send a list of messages once.
04: send a single message repeatedly. 05: send a list of messages repeatedly. 00,06-FF: reserved.

### 3.6.1 Stop message transmission mode

SYNC | LENGTH HB | LENGTH LB | DATA CODE | SUB-DATA CODE | PAYLOAD | CHECKSUM
3D | 00 | 02 | 16 | 01 | | 19

Table 31. Stop message transmission request frame.

DATA CODE byte:
16 = 00010110b
00b: source – USB
01b: target – CCD-bus
0110b: command – message Tx
SYNC | LENGTH HB | LENGTH LB | DATA CODE | SUB-DATA CODE | PAYLOAD | CHECKSUM
3D | 00 | 04 | 06 | 01 | 00 01 | 0C

Table 32. Stop message transmission response frame.

PAYLOAD offset:
00: response state (00: ok, FF: error).
01: target bus (01: CCD-bus, 02: SCI-bus PCM, 03: SCI-bus TCM).

### 3.6.2 Send a single message once mode

SYNC | LENGTH HB | LENGTH LB | DATA CODE | SUB-DATA CODE | PAYLOAD | CHECKSUM
3D | 00 | 06 | 16 | 02 | E4 00 00 E4 | E6

Table 33. Send a single message once frame.

DATA CODE byte:
16 = 00010110b
00b: source – USB
01b: target – CCD-bus
0110b: command – message Tx

PAYLOAD bytes(s):
E4 00 00 E4: message to be transmitted on the target bus.

SYNC | LENGTH HB | LENGTH LB | DATA CODE | SUB-DATA CODE | PAYLOAD | CHECKSUM
3D | 00 | 04 | 06 | 02 | 00 01 | 0D

Table 34. Send a single message once acknowledgment frame.

PAYLOAD offset:
00: acknowledgment state (00: ok, FF: error).
01: target bus (01: CCD-bus, 02: SCI-bus PCM, 03: SCI-bus TCM).

This response frame acknowledges that the message transmission request has been processed and the message is waiting in the transmit buffer.
Normally transmission occurs almost immediately and a second frame is received containing a timestamp and the received message.
SYNC | LENGTH HB | LENGTH LB | DATA CODE | SUB-DATA CODE | PAYLOAD | CHECKSUM
3D | 00 | 0A | 47 | 02 | 00 53 88 06 E4 00 00 E4 | FC

Table 35. Message received frame.

DATA CODE byte:
47 = 01010110b
01b: source – CCD-bus
00b: target – USB
0111b: command – message Rx

PAYLOAD offset:
00-03: timestamp in milliseconds, 00 53 88 06 = 5474310 ms = 01:31:14.310. 04-07: received message from source bus, E4 00 00 E4.

This type of frame is received for every kind of transmission modes regardless of list transmission and message repeating.

### 3.6.3 Send a list of messages once mode

SYNC | LENGTH HB | LENGTH LB | DATA CODE | SUB-DATA CODE | PAYLOAD | CHECKSUM
3D | 00 | 0E | 16 | 03 | 00 02 04 24 00 00 24 04 E4 00 00 E4 | 41

Table 36. Send a list of messages once frame.

DATA CODE byte:
16 = 00010110b
00b: source – USB
01b: target – CCD-bus
0110b: command – message Tx

PAYLOAD offset:
00: message iteration state (00: disabled, 01: enabled), for this mode it reads always 00.
01: number of messages in the list, 02: 2 messages.

02: first message length, 04: 4 bytes.
03-06: first message to be transmitted on the target bus, 24 00 00 24. 07: second message length.
08-0B: second message to be transmitted on the target bus, E4 00 00 E4.

The list goes on similarly: every message is preceded with its length.

The delay value between messages is taken from the repeat behavior settings, which is 100 ms by default.

SYNC | LENGTH HB | LENGTH LB | DATA CODE | SUB-DATA CODE | PAYLOAD | CHECKSUM
3D | 00 | 04 | 06 | 03 | 00 01 | 0E

Table 37. Send a list of messages once acknowledgment frame.

PAYLOAD offset:
00: acknowledgment state (00: ok, FF: error).
01: target bus (01: CCD-bus, 02: SCI-bus PCM, 03: SCI-bus TCM).

The following frames are marked as single messages described in Table 35.

### 3.6.4 Send a single message repeatedly mode

SYNC | LENGTH HB | LENGTH LB | DATA CODE | SUB-DATA CODE | PAYLOAD | CHECKSUM
3D | 00 | 09 | 16 | 04 | 00 01 04 24 00 00 24 | 70

Table 38. Send a single message repeatedly frame.

DATA CODE byte:
16 = 00010110b
00b: source – USB
01b: target – CCD-bus
0110b: command – message Tx

PAYLOAD offset:
00: message iteration state (00: disabled, 01: enabled).
01: number of messages in the list, 01: 1 message.
02: message length, 04: 4 bytes.
03-06: message to be transmitted on the target bus, 24 00 00 24.

The delay between messages is taken from the repeat behavior settings, which is 100 ms by default.

SYNC | LENGTH HB | LENGTH LB | DATA CODE | SUB-DATA CODE | PAYLOAD | CHECKSUM
3D | 00 | 04 | 06 | 04 | 00 01 | 0F

Table 39. Send a single message repeatedly acknowledgment frame.

PAYLOAD offset:
00: acknowledgment state (00: ok, FF: error).
01: target bus (01: CCD-bus, 02: SCI-bus PCM, 03: SCI-bus TCM).

### 3.6.4.1 Send iterated messages mode

This is a special mode in which start/end messages are provided and the start message is incremented for every repeat until the ending message is reached. For CCD-bus the B2-request message can be incremented only. SCI-bus is more flexible but still limited to a maximum of 4-bytes message length. This special mode is useful for automatic ROM readings or when a range of values need to be read once.
The delay between messages and the increment value is taken from the repeat behavior setting. Defaults: delay = 100 ms, increment = 2 for CCD-bus, 1 for SCI-bus. CCD-bus message increment is 2 because for one ROM value request actually two bytes are returned and it is enough to read every second address.
SYNC | LENGTH HB | LENGTH LB | DATA CODE | SUB-DATA CODE | PAYLOAD | CHECKSUM
3D | 00 | 11 | 16 | 04 | 01 01 06 B2 20 22 00 00 F4 B2 20 22 FF FE F1 | FD

Table 40. Send iterated messages to the CCD-bus frame.

DATA CODE byte:
16 = 00010110b
00b: source – USB
01b: target – CCD-bus
0110b: command – message Tx

PAYLOAD offset:
00: | message iteration state (00: disabled, 01: enabled).
01: | number of messages in the list, 01: 1 message.
02: | message length, 06: 6 bytes.
03-08: starting message to be transmitted on the target bus, B2 20 22 00 00 F4. 09-0E: ending message to be transmitted on the target bus, B2 20 22 FF FE F1.

Note that the message length only appears once. Also in this special case only the 4th and 5th bytes (known as request/response parameters) are considered for incrementing.

This particular example requests ROM values from the Body Control Module (BCM). Its ROM has a 16-bit address space so requested addresses range between 00 00 and FF FE. Since the response message (F2) has also two parameters therefore 2 bytes are returned: 1 byte at the requested ROM location and the next byte.

SYNC | LENGTH HB | LENGTH LB | DATA CODE | SUB-DATA CODE | PAYLOAD | CHECKSUM
3D | 00 | 04 | 06 | 04 | 00 01 | 0F

Table 41. Send iterated messages to the CCD-bus acknowledgment frame.

PAYLOAD offset:
00: acknowledgment state (00: ok, FF: error).
01: target bus (01: CCD-bus, 02: SCI-bus PCM, 03: SCI-bus TCM).
SYNC | LENGTH HB | LENGTH LB | DATA CODE | SUB-DATA CODE | PAYLOAD | CHECKSUM
3D | 00 | 0D | 26 | 04 | 01 01 04 26 00 00 00 26 01 FF FF | 88

Table 42. Send iterated messages to the SCI-bus frame.

DATA CODE byte:
26 = 00100110b
00b: source – USB
10b: target – SCI-bus (PCM) 0110b: command – message Tx

PAYLOAD offset:
00: | message iteration state (00: disabled, 01: enabled).
01: | number of messages in the list, 01: 1 message.
02: | message length, 04: 4 bytes.
03-08: starting message to be transmitted on the target bus, 26 00 00 00. 09-0E: ending message to be transmitted on the target bus, 26 01 FF FF.

Note that the message length only appears once. Possible message lengths are 1-4 bytes.

SYNC | LENGTH HB | LENGTH LB | DATA CODE | SUB-DATA CODE | PAYLOAD | CHECKSUM
3D | 00 | 04 | 06 | 04 | 00 02 | 10

Table 43. Send iterated messages acknowledgment frame.

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

### 3.6.5 Send a list of messages repeatedly mode

SYNC | LENGTH HB | LENGTH LB | DATA CODE | SUB-DATA CODE | PAYLOAD | CHECKSUM
3D | 00 | 0E | 16 | 05 | 00 02 04 24 00 00 24 04 E4 00 00 E4 | 43

Table 44. Send a list of messages repeatedly frame.

DATA CODE byte:
16 = 00010110b
00b: source – USB
01b: target – CCD-bus
0110b: command – message Tx

PAYLOAD offset:
00: | message iteration state (00: disabled, 01: enabled).
01: | number of messages in the list, 02: 2 messages.
02: | first message length, 04: 4 bytes.
03-06: first message to be transmitted on the target bus, 24 00 00 24. 07: second message length.
08-0B: second message to be transmitted on the target bus, E4 00 00 E4.

The list goes on similarly: every message is preceded with its length.

SYNC | LENGTH HB | LENGTH LB | DATA CODE | SUB-DATA CODE | PAYLOAD | CHECKSUM
3D | 00 | 04 | 06 | 04 | 00 01 | 0F

Table 45. Send a list messages repeatedly acknowledgment frame.

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

### 3.7 Debug (command: 0E)

Applicable SUB-DATA CODE bytes (modes):
01: generate random CCD-bus messages.
02: read internal EEPROM byte.
03: read internal EEPROM block.
04: read external EEPROM byte.
05: read external EEPROM block. 06: write internal EEPROM byte. 07: write internal EEPROM block. 08: write external EEPROM byte.
09: write external EEPROM block.
00,0A-FF: reserved.

### 3.7.1 Generate random CCD-bus messages mode

This feature is useful for bench-testing the scanner’s internal CCD-bus circuits. However, the random generated messages may confuse modules on a live CCD-bus network. Use this debug mode carefully.

SYNC | LENGTH HB | LENGTH LB | DATA CODE | SUB-DATA CODE | PAYLOAD | CHECKSUM
3D | 00 | 07 | 0E | 01 | 01 00 64 01 F4 | 70

Table 46. Send random CCD-bus messages frame.

PAYLOAD offset:
00: state (00: disabled, 01: enabled).
00-01: minimum interval in milliseconds between two random messages,
| 00 64 = 100 ms.
02-03: maximum interval in milliseconds between two random messages,
| 01 F4 = 500 ms.

Minimum interval should be no less than 20 ms because CCD-bus load is near 100% at this value. Message lengths are fixed between 3 and 6 bytes to make the messages look more authentic.

SYNC | LENGTH HB | LENGTH LB | DATA CODE | SUB-DATA CODE | PAYLOAD | CHECKSUM
3D | 00 | 04 | 0E | 01 | 00 01 | 14

Table 47. Send random CCD-bus messages acknowledgment frame.

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

### 3.7.2 Read internal EEPROM byte mode

SYNC | LENGTH HB | LENGTH LB | DATA CODE | SUB-DATA CODE | PAYLOAD | CHECKSUM
3D | 00 | 04 | 0E | 02 | 00 00 | 14

Table 48. Read internal EEPROM byte frame.

PAYLOAD offset:
00-01: internal EEPROM offset, 00 00.

Possible offset for the ATmega2560 MCU range between 00 00 and 0F FF (4 kB).

SYNC | LENGTH HB | LENGTH LB | DATA CODE | SUB-DATA CODE | PAYLOAD | CHECKSUM
3D | 00 | 06 | 0E | 02 | 00 00 00 00 | 16

Table 49. Read internal EEPROM byte response frame.

PAYLOAD offset:
00: response state (00: ok, FF: error). 01-02: internal EEPROM offset.
03: value at the given offset, 00.

### 3.7.3 Read internal EEPROM block mode

SYNC | LENGTH HB | LENGTH LB | DATA CODE | SUB-DATA CODE | PAYLOAD | CHECKSUM
3D | 00 | 06 | 0E | 03 | 00 00 00 02 | 19

Table 50. Read internal EEPROM block frame.

PAYLOAD offset:
00-01: internal EEPROM offset, 00 00.
02-03: number of bytes to read, 00 02 = 2 bytes.
SYNC | LENGTH HB | LENGTH LB | DATA CODE | SUB-DATA CODE | PAYLOAD | CHECKSUM
3D | 00 | 07 | 0E | 03 | 00 00 00 00 00 | 18

Table 51. Read internal EEPROM block response frame.

PAYLOAD offset:
00: response state (00: ok, FF: error). 01-02: internal EEPROM offset.
03: | value at the given offset, 00.
04: | value at next address, 00.
XX: | value at a further consecutive address.

### 3.7.4 Read external EEPROM byte mode

SYNC | LENGTH HB | LENGTH LB | DATA CODE | SUB-DATA CODE | PAYLOAD | CHECKSUM
3D | 00 | 04 | 0E | 04 | 00 00 | 16

Table 52. Read external EEPROM byte frame.

PAYLOAD offset:
00-01: external EEPROM offset, 00 00.

Possible offsets for the 24LC32A chip range between 00 00 and 0F FF (4 kB).

SYNC | LENGTH HB | LENGTH LB | DATA CODE | SUB-DATA CODE | PAYLOAD | CHECKSUM
3D | 00 | 06 | 0E | 04 | 00 00 00 00 | 18

Table 53. Read external EEPROM byte response frame.

PAYLOAD offset:
00: response state (00: ok, FF: error). 01-02: external EEPROM offset.
03: value at the given offset, 00.

### 3.7.5 Read external EEPROM block mode

SYNC | LENGTH HB | LENGTH LB | DATA CODE | SUB-DATA CODE | PAYLOAD | CHECKSUM
3D | 00 | 06 | 0E | 05 | 00 00 00 02 | 1B

Table 54. Read external EEPROM block frame.

PAYLOAD offset:
00-01: external EEPROM offset, 00 00.
02-03: number of bytes to read, 00 02 = 2 bytes.
SYNC | LENGTH HB | LENGTH LB | DATA CODE | SUB-DATA CODE | PAYLOAD | CHECKSUM
3D | 00 | 07 | 0E | 05 | 00 00 00 00 8C | A6

Table 55. Read external EEPROM block response frame.

PAYLOAD offset:
00: response state (00: ok, FF: error). 01-02: external EEPROM offset.
03: | value at the given offset, 00.
04: | value at next address, 8C.
XX: | value at a further consecutive address.

### 3.7.6 Write internal EEPROM byte mode

SYNC | LENGTH HB | LENGTH LB | DATA CODE | SUB-DATA CODE | PAYLOAD | CHECKSUM
3D | 00 | 05 | 0E | 06 | 00 00 00 | 19

Table 56. Write internal EEPROM byte frame.

PAYLOAD offset:
00-01: internal EEPROM offset, 00 00. 02: value to write, 00.
SYNC | LENGTH HB | LENGTH LB | DATA CODE | SUB-DATA CODE | PAYLOAD | CHECKSUM
3D | 00 | 06 | 0E | 06 | 00 00 00 00 | 16

Table 57. Write internal EEPROM byte response frame.

PAYLOAD offset:
00: response state (00: ok, FF: error). 01-02: internal EEPROM offset.
03: value confirmation at the given offset, 00.

### 3.7.7 Write internal EEPROM block mode

SYNC | LENGTH HB | LENGTH LB | DATA CODE | SUB-DATA CODE | PAYLOAD | CHECKSUM
3D | 00 | 06 | 0E | 07 | 00 00 00 00 | 1B

Table 58. Write internal EEPROM block frame.

PAYLOAD offset:
00-01: internal EEPROM offset, 00 00.
02: value to write at offset, 00.
03: value to write at next address, 00.
XX: further value to write at next consecutive address.
SYNC | LENGTH HB | LENGTH LB | DATA CODE | SUB-DATA CODE | PAYLOAD | CHECKSUM
3D | 00 | 07 | 0E | 07 | 00 00 00 00 00 | 1C

Table 59. Write internal EEPROM block response frame.

PAYLOAD offset:
00: response state (00: ok, FF: error).
01-02: internal EEPROM offset.
03: | EEPROM value confirmation at the given offset, 00.
04: | EEPROM value confirmation at the next address, 00.
XX: | value confirmation at next consecutive address.

### 3.7.8 Write external EEPROM byte mode

SYNC | LENGTH HB | LENGTH LB | DATA CODE | SUB-DATA CODE | PAYLOAD | CHECKSUM
3D | 00 | 05 | 0E | 08 | 00 00 00 | 1B

Table 60. Write external EEPROM byte frame. PAYLOAD offset:
00-01: external EEPROM offset, 00 00. 02: value to write, 00.
SYNC | LENGTH HB | LENGTH LB | DATA CODE | SUB-DATA CODE | PAYLOAD | CHECKSUM
3D | 00 | 06 | 0E | 08 | 00 00 00 00 | 1C

Table 61. Write external EEPROM byte response frame.

PAYLOAD offset:
00: response state (00: ok, FF: error).
01-02: external EEPROM offset.
03: EEPROM value confirmation at the given offset, 00.

### 3.7.9 Write external EEPROM block mode

SYNC | LENGTH HB | LENGTH LB | DATA CODE | SUB-DATA CODE | PAYLOAD | CHECKSUM
3D | 00 | 06 | 0E | 09 | 00 00 00 8C | A9

Table 62. Write external EEPROM block frame.

PAYLOAD offset:
00-01: external EEPROM offset, 00 00.
02: value to write at offset, 00.
03: value to write at next address, 8C.
XX: further value to write at next consecutive address.
SYNC | LENGTH HB | LENGTH LB | DATA CODE | SUB-DATA CODE | PAYLOAD | CHECKSUM
3D | 00 | 07 | 0E | 09 | 00 00 00 00 8C | AA

Table 63. Write external EEPROM block response frame.

PAYLOAD offset:
00: response state (00: ok, FF: error). 01-02: external EEPROM offset.
03: | value confirmation at the given offset, 00.
04: | value confirmation at next address, 00.
XX: | value confirmation at next consecutive address.

### 3.8 Error (command: 0F)

Applicable SUB-DATA CODE bytes (modes): 01: invalid frame length value.
02: invalid DATA CODE byte command. 03: invalid SUB-DATA CODE byte value. 04: invalid PAYLOAD values.
05: invalid frame checksum value. 06: frame timeout occurred.
07: buffer overflow.
08-F6: reserved.
F7: not enough MCU RAM.
F8: no response from SCI-bus high-speed memory table. F9: invalid SCI-bus high-speed memory table.
FA: no response from SCI-bus high-speed mode.
FB: external EEPROM not found.
FC: external EEPROM read error.
FD: external EEPROM write error.
FE: internal error.
FF: fatal error.

### 3.8.1 Invalid frame length value mode

Due to the ATmega2560 microcontroller’s limited RAM size the maximum receivable frame length is limited to 1024 bytes. Also the minimum meaningful frame length is 6 bytes. Whenever these conditions are violated (frame length less then 6 bytes or more than 1024 bytes) the scanner sends this error frame back to the host computer.

### 3.8.2 Invalid DATA CODE byte command mode

When unused/reserved commands (08-0D) are being called this error frame is sent as a response.

### 3.8.3 Invalid SUB-DATA CODE byte value mode

Depending on the particular command when unused/reserved modes are being called this error frame is sent as a response.

### 3.8.4 Invalid PAYLOAD values mode

If a frame sent to the scanner does not contain the required number of payload bytes then this error frame is sent as a response. More payload bytes are not a problem, because the scanner discards extra bytes and processes the necessary bytes only.

### 3.8.5 Invalid frame checksum value mode

The scanner verifies every received frame by calculating what the checksum byte at the end of the frame should be. If this value does not equal to the received checksum byte then this error frame is sent as a response.

### 3.8.6 Frame timeout occurred mode

When the scanner received the frame length bytes it calculates how much more bytes it should receive until the frame ends. If the remaining frame bytes do not arrive within 100 milliseconds then this error frame is sent back to the host computer.

### 3.8.7 Buffer overflow mode

Whenever an applicable buffer in the scanner firmware tries to store more data than its size then this error frame is sent as a response.

### 3.8.8 Not enough MCU RAM mode

Due to the ATmega2560 microcontroller’s limited RAM size there is a certain upper limit of the length of outgoing frames. This length is calculated every time before a frame is assembled to avoid freezing and RAM issues. Whenever such event occurs the MCU returns this error frame before anything bad could happen. Easiest way to trigger this error if several kilobytes of EEPROM data are requested at once.

### 3.8.9 No response from SCI-bus high-speed memory table mode

Not all memory tables are accessible through the high-speed mode of the SCI-bus. When no echo is heard from a memory table this error frame is sent as a response.

### 3.8.10 Invalid SCI-bus high-speed memory table mode

Valid high-speed mode memory tables range between F0 and FF, except FE which makes the engine controller return to low-speed mode. If values other than that are received by the scanner as first message byte then this error frame is sent as a response.
It is worth noting that the engine controller itself does not mind if a RAM value request message does not start with a memory table identifier. This condition is enforced to make every request/response message as clear as possible.

### 3.8.11 No response from SCI-bus high-speed mode

In high-speed mode if a RAM value cannot be read within a certain timeout limit (5-20 milliseconds) then this error frame is sent as a response.

### 3.8.12 External EEPROM not found mode

The diagnostic scanner uses an external EEPROM chip for settings storage and it is initialized every time the scanner resets. If the chip cannot be initialized at startup then this error frame is sent.

### 3.8.13 External EEPROM read error mode

If the external EEPROM cannot be read for some reason then this error frame is sent as a response.

### 3.8.14 External EEPROM write error mode

If the external EEPROM cannot be written for some reason then this error frame is sent as a response.

### 3.8.15 Internal error mode

When the scanner experiences an unhandled timeout this error frame is sent back to the host computer.

### 3.8.16 Fatal error mode

When something goes horribly wrong in the firmware of the diagnostic scanner, then this error frame is sent back to the host computer.

## 4. Revision history

2020.09.01: original.

2020.09.09:
- add: LCD I2C address to status response (Table 10),
- add: LCD I2C address to LCD settings (Table 19 and 20).

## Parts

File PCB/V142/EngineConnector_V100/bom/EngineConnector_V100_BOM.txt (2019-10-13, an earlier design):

https://www.ebay.com/itm/163452543862
4x 6.3 mm

https://www.ebay.com/itm/292556796042
1x 4PIN

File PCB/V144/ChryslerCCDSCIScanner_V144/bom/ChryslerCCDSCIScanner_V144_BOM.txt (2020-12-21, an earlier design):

ChryslerCCDSCIScanner_V144_BOM

Part  Value           Device                                       Package
-------------------------------------------------------------------------------------------
C1    10uF            C-EU                                         1206
C2    100uF           C_POL-EU                                     8X8X10.5-SMD
C3    100uF           C_POL-EU                                     8X8X10.5-SMD
C4    0.1uF           C-EU                                         1206
C5    1uF             C-EU                                         1206
C6    0.1uF           C-EU                                         1206
C7    0.1uF           C-EU                                         1206
C8    0.1uF           C-EU                                         1206
C9    22pF            C-EU                                         1206
C10   22pF            C-EU                                         1206
C11   0.1uF           C-EU                                         1206
C12   0.1uF           C-EU                                         1206
C13   0.1uF           C-EU                                         1206
C14   0.1uF           C-EU                                         1206
C15   0.1uF           C-EU                                         1206
C16   0.1uF           C-EU                                         1206
C17   0.1uF           C-EU                                         1206
C18   470pF           C-EU                                         1206
C19   0.1uF           C-EU                                         1206
C20   470pF           C-EU                                         1206
C21   0.1uF           C-EU                                         1206
C22   0.1uF           C-EU                                         1206
C23   3.3nF           C-EU                                         1206
C24   3.3nF           C-EU                                         1206
CN1   OBD2            OBD2                                         OBD2-90
D1    RED             LED                                          1206
D2    ORANGE          LED                                          1206
D3    GREEN           LED                                          1206
D4    BLUE            LED                                          1206
D5    SS34            SCHOTTKY_DIODE                               DO214AC
D6    1N4148          D-EU                                         1206
D7    SS34            SCHOTTKY_DIODE                               DO214AC
D8    BZV55C4V7       ZENER_DIODE                                  1206
D9    BZV55C4V7       ZENER_DIODE                                  1206
E1    ESDCAN24-2BLY   ESDCANXX                                     SOT23-3
IC1   LM2576S-5.0     LM2576S                                      TO263-5
J1    GS              PINHD                                        1X03
J2    ISP-10          PROGRAMMER_ISP-10                            ZL231-10PG
J3    I2C             CONNECTOR_4P                                 XH2.54-4P-HORIZONTAL-SMD
J4    EXT_5V          CONNECTOR_2P                                 XH2.54-2P-HORIZONTAL-SMD
J5    FTDI            CONNECTOR_6P                                 XH2.54-6P-HORIZONTAL-SMD
J6    RSS             PINHD                                        1X03
L1    100uH           L-EU                                         CD127
L2    10uH            L-EU                                         1206
N1    AO3400          N-MOSFET                                     SOT23-3
P1    AO3401          P-MOSFET                                     SOT23-3
P2    AO3401          P-MOSFET                                     SOT23-3
Q1    16MHz           CRYSTAL_OSCILLATOR                           HC49/SMD
R1    180             R-EU                                         1206
R2    180             R-EU                                         1206
R3    1k              R-EU                                         1206
R4    180             R-EU                                         1206
R5    10              R-EU                                         1206
R6    10              R-EU                                         1206
R7    10k             R-EU                                         1206
R8    0               R-EU                                         1206
R9    120             R-EU                                         1206
R10   13k             R-EU                                         1206
R11   13k             R-EU                                         1206
R12   10k             R-EU                                         1206
R13   10k             R-EU                                         1206
R14   22k             R-EU                                         1206
R15   47k             R-EU                                         1206
R16   10k             R-EU                                         1206
R17   1k              R-EU                                         1206
R18   1k              R-EU                                         1206
R19   27k             R-EU                                         1206
R20   5k              R-EU                                         1206
R21   10k             R-EU                                         1206
R22   4k7             R-EU                                         1206
R23   4k7             R-EU                                         1206
R24   360             R-EU                                         1206
R25   360             R-EU                                         1206
R26   10k             R-EU                                         1206
R27   10k             R-EU                                         1206
R28   10k             R-EU                                         1206
R29   10k             R-EU                                         1206
S1    POWER           SWITCH                                       SL19-123
S2    RESET           TACT_SWITCH                                  6X6X5MM-SMD
U1    ATMEGA2560-16AU ATMEGA2560-16AU                              TQFP100
U2    CP2102          CP210X_USB_UART                              QFN28
U3    IRF7317         IRF7317                                      SOIC-8
U4    74HC4066        4066D                                        SOIC-14
U5    74HC4066        4066D                                        SOIC-14
U6    24LC32A         EEPROM                                       SOIC-8
U7    USBLC6-2SC6     USBLC6-2SC6                                  SOT23-6
U8    LM393D          LM393D                                       SOIC-8
USB   MICRO_USB       USB                                          USB-B-MICRO-THT

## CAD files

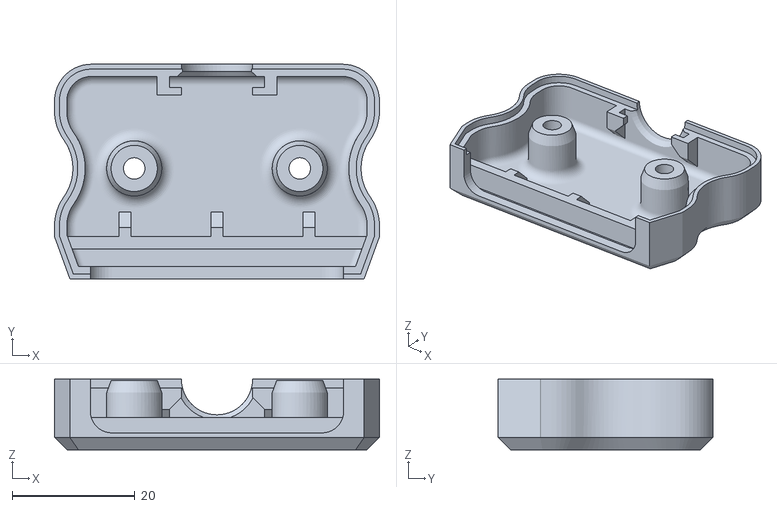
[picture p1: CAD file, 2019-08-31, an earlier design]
PCB/V140/box/OBD-II_adapter_top.STL
53.0 x 35.0 x 11.5

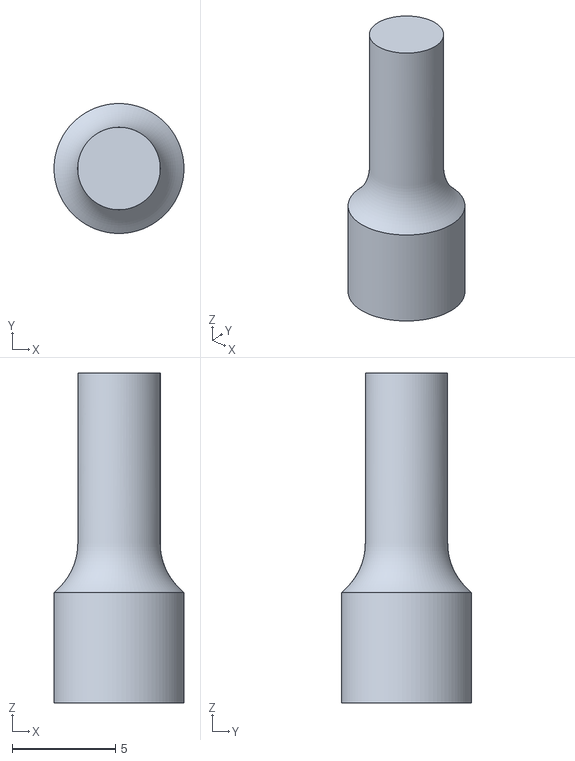
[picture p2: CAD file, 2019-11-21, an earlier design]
PCB/V142/3D-printed_parts/V142_reset_button.STL
6.30 x 6.30 x 16.0

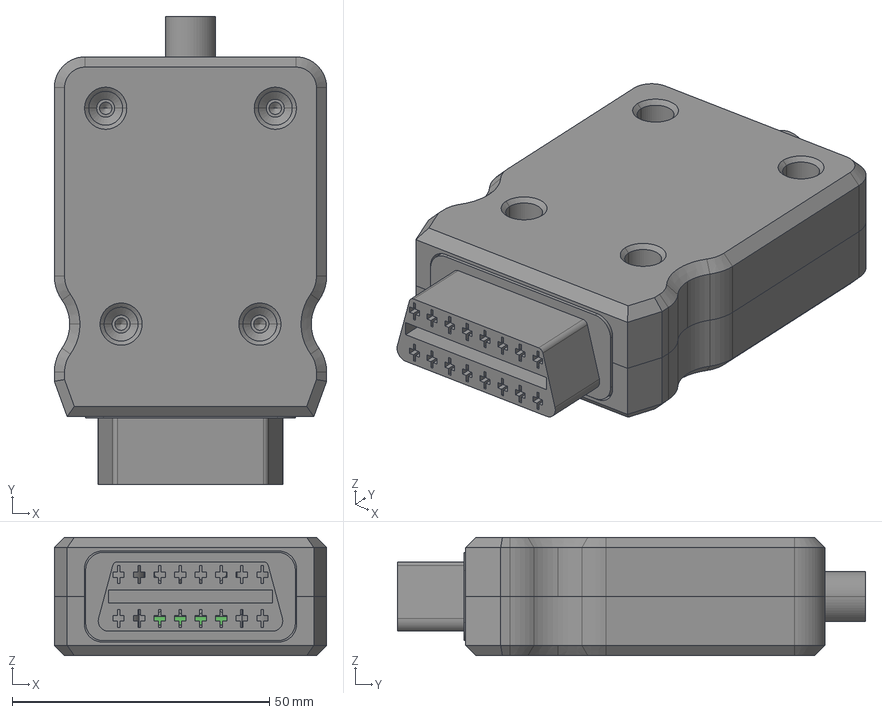
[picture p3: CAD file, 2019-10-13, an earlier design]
PCB/V142/Assemblies/OBD2_female_connector_02.STEP
53.0 x 91.0 x 23.0 mm
OBD2_connector_bottom_02
OBD2_connector_top_02
OBD2_cable_holder
SEP-A-OBD-D
OBD2_SCI_PCB

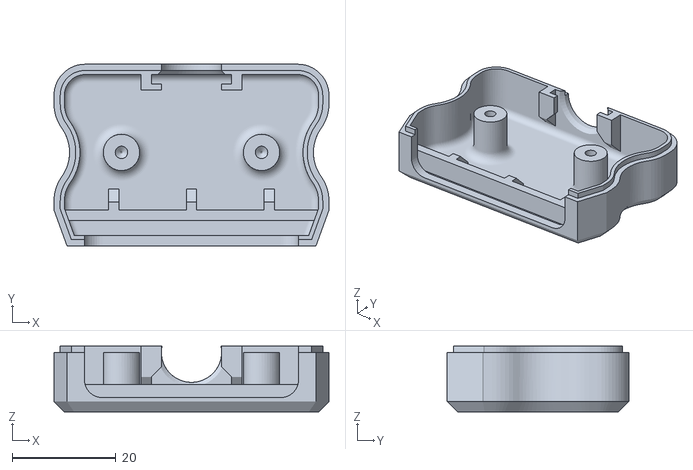
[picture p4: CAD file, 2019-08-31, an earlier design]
PCB/V140/box/OBD-II_adapter_bottom.STL
53.0 x 35.0 x 12.7

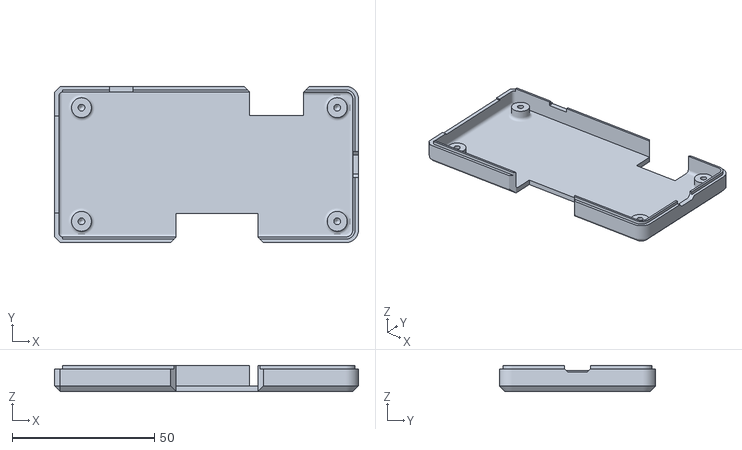
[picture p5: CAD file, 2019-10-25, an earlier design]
PCB/V142/3D-printed_parts/V142_box_bottom.STL
107.0 x 55.0 x 9.20

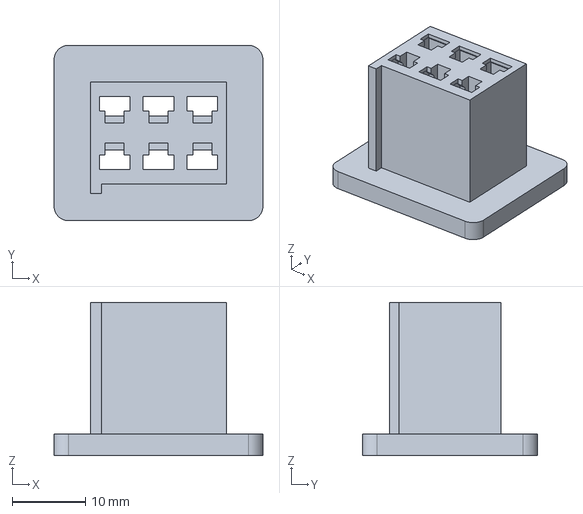
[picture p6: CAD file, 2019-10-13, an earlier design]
PCB/V142/Assemblies/OBD1_6-pin_female_CCD_DLC.STEP
28.6 x 24.0 x 21.0 mm

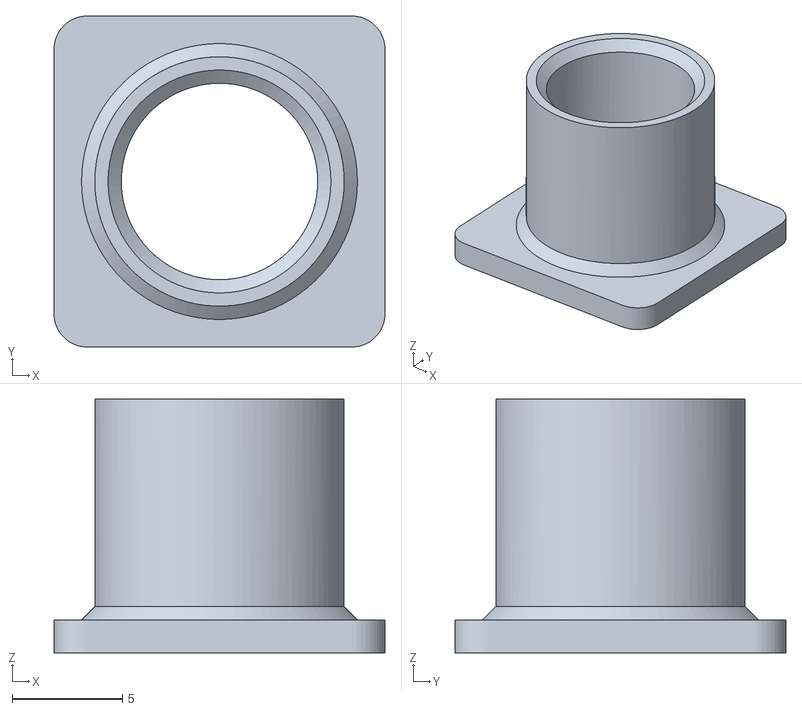
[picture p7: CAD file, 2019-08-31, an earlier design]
PCB/V140/box/OBD-II_cable_holder.STL
15.0 x 15.0 x 11.5

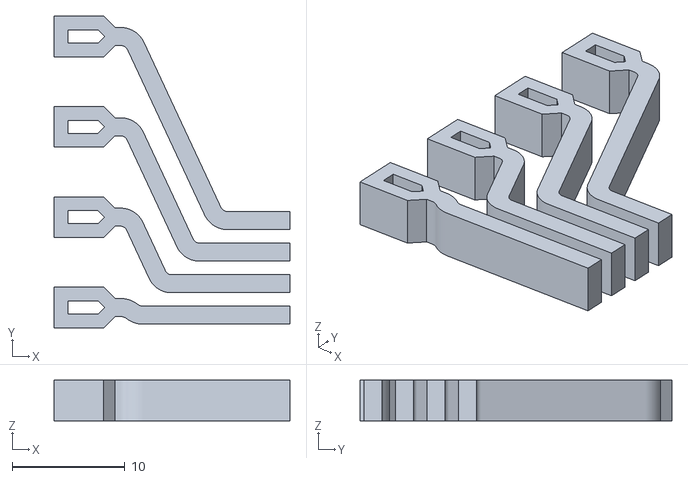
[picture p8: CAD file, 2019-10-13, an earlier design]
PCB/V142/3D-printed_parts/V142_LED_extender_transparent.STL
20.9 x 27.6 x 3.60

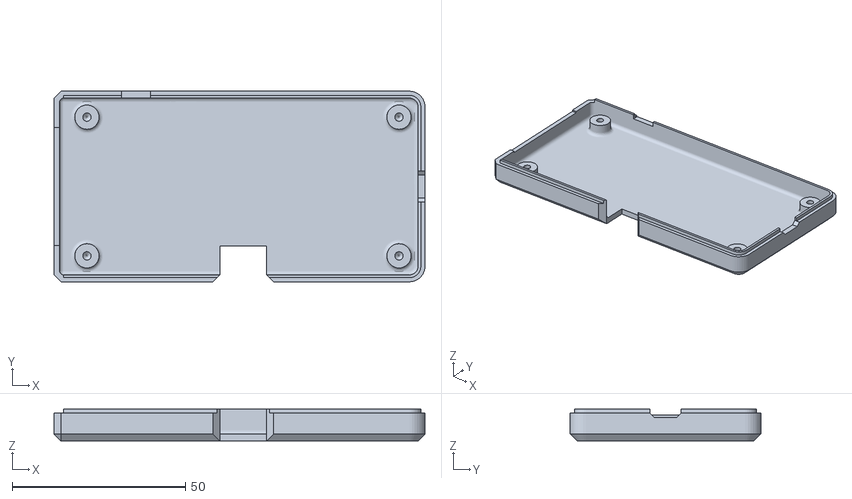
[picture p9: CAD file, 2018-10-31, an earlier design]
PCB/V140/box/box_bottom.STL
107.0 x 55.0 x 9.20

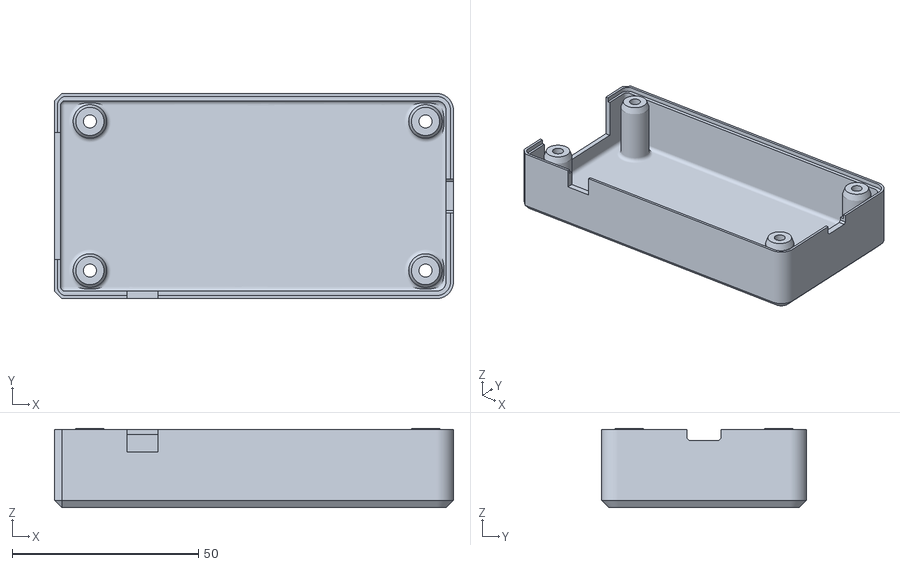
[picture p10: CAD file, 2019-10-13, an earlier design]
PCB/V142/3D-printed_parts/V142_box_top_raw.STL
107.0 x 55.0 x 21.3

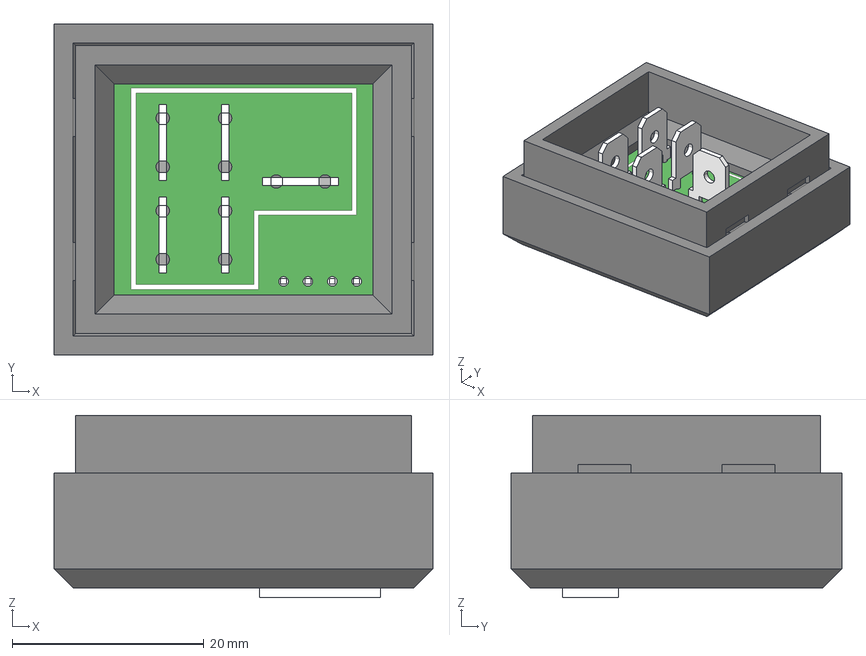
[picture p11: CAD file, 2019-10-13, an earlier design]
PCB/V142/Assemblies/OBD1_5-pin_male_SCI_DLC.STEP
39.5 x 34.5 x 19.0 mm
OBD1_5-pin_male_SCI_DLC_PCB_V100
OBD1_5-pin_male_SCI_DLC_male_pin x 5
OBD1_5-pin_male_SCI_DLC_XH2.54-4P_male_pin
OBD1_5-pin_male_SCI_DLC_bottom
OBD1_5-pin_male_SCI_DLC_top

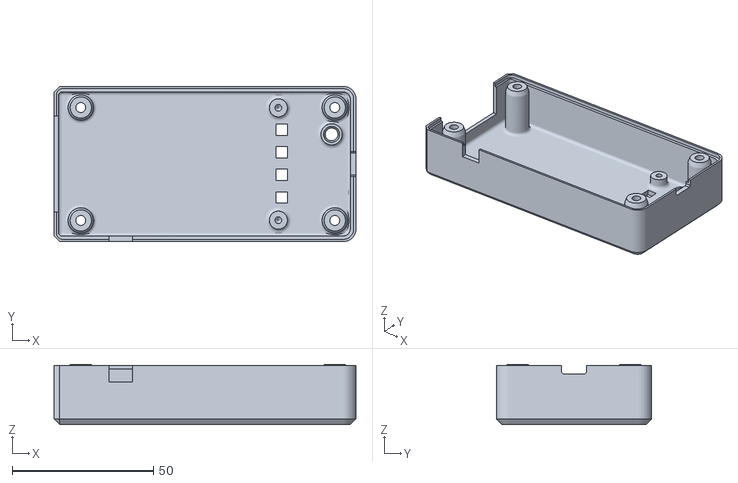
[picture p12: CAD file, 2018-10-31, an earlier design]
PCB/V140/box/box_top.STL
107.0 x 55.0 x 21.3

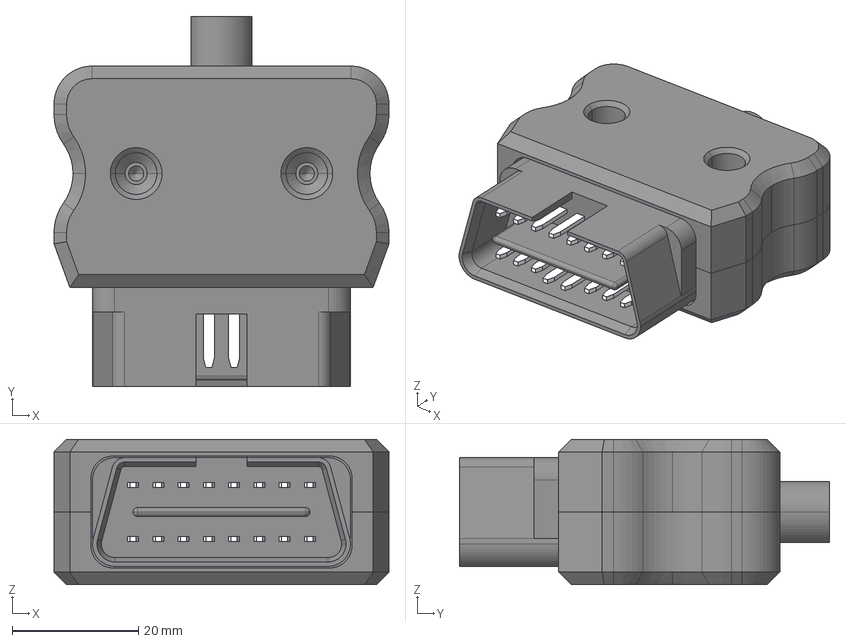
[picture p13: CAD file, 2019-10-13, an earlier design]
PCB/V142/Assemblies/OBD2_male_connector_01.STEP
53.0 x 58.5 x 23.0 mm
OBD2_connector_bottom_01
OBD2_connector_top_01
OBD2_cable_holder
SEP-A-OBD-E

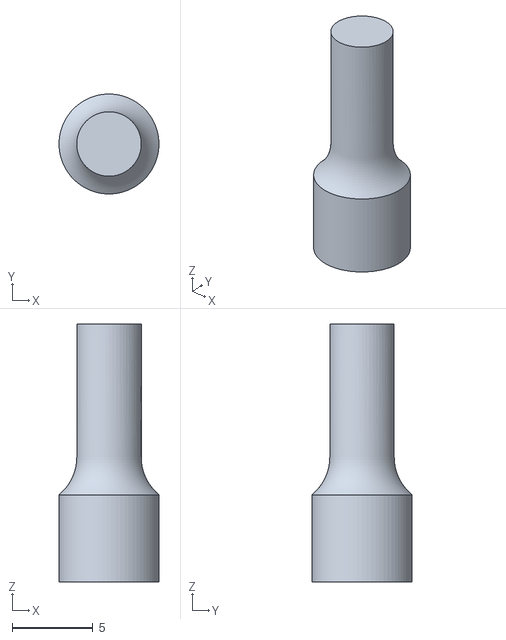
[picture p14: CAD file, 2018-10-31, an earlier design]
PCB/V140/box/reset_button.STL
6.20 x 6.19 x 16.0

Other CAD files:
PCB/V142/3D-printed_parts/OBD1_6-pin_female_CCD_DLC.STL
PCB/V142/Assemblies/OBD2_female_connector_01.STEP
PCB/V140/box/box_top_raw.STL
PCB/V140/box/led_extender_fixture.STL
PCB/V140/box/led_extender_transparent.STL
PCB/V142/3D-printed_parts/OBD1_5-pin_male_SCI_DLC_bottom.STL
PCB/V142/3D-printed_parts/OBD1_5-pin_male_SCI_DLC_top.STL
PCB/V142/3D-printed_parts/OBD2_cable_holder.STL
PCB/V142/3D-printed_parts/OBD2_connector_bottom_01.STL
PCB/V142/3D-printed_parts/OBD2_connector_bottom_02.STL
PCB/V142/3D-printed_parts/OBD2_connector_top_01.STL
PCB/V142/3D-printed_parts/OBD2_connector_top_02.STL
PCB/V142/3D-printed_parts/V142_LED_extender_fixture.STL

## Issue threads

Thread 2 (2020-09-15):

Missing BOM for V1.44

viper-666, 2020-09-15:
Hello,
can you please provide the BOM for the Hardware V1.44.
Thanks!!!
Andre

laszlodaniel, 2020-09-15:
Will do in the coming days.
I want to do it in text format instead of html and this needs formatting consideration.

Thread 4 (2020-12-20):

[Arduino] SCI-bus low-speed diagnostic mode 14 repeated messages issue

laszlodaniel, 2020-12-20:
For every 2 bytes sent in mode 14 (ex. 14 07) the scanner expects a third byte from the the engine controller after the echos (ex. 14 07 FF). When a third byte is not received the scanner tries to send the original 2 bytes again 10 times, then gives up.

In repeated message list mode (more than 1 request, ex. 14 07, 14 08, 14 09, 14 0A) the scanner interrupts the whole repeated session when the engine controller does not return any value for a single request.

It would be better to skip the non-responsive request after 10 retries to continue the session.

Closed 2020-12-24.

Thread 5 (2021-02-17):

Missing Library

jay-wilkinson, 2021-02-17:
The link on page https://github.com/laszlodaniel/ChryslerCCDSCIScanner/tree/master/Arduino/GettingStarted , in the main sketch, etc. seems to be dead. (https://bitbucket.org/fmalpartida/new-liquidcrystal/downloads/)

laszlodaniel, 2021-02-17:
Thanks for letting me know! The Arduino sketch structure changed since then and the library was replaced by another one. You can download the current I2C LCD library from here:
https://github.com/fdebrabander/Arduino-LiquidCrystal-I2C-library

The same link can be found in the lcd.h file.

jay-wilkinson, 2021-02-17:
Thanks for the quick response!

Closed 2021-02-17.

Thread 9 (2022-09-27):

Feature request: Log responses as CSV

dino2gnt, 2022-09-27:
When sending repeated commands, such as fetching parameters via SCI CMD 14 in the Engine Tools interface, it would be most excellent if the scanner application could optionally write the responses to CSV so that a user could see how the values change over time (and potentially graph them)

For example, i send a request for 0x1412, 0x1415, and 0x1416:
```
3D 00 0C 26 05 03 02 14 12 02 14 15 02 14 16 F8
```
The responses could be written out:
```
epochmillis,1412,1415,1416
epochmillis,03,11,00
epochmillis,03,10,00
epochmillis,05,11,00
[ ... ]
epochmillis,05,11,00
epochmillis,1412,1415,1416
epochmillis,08,16,00
[ ... ]
```
Where `epochmillis` is a milisecond epoch timestamp, and the header `epochmillis,1412,1415,1416` could be logged on an interval every X samples or every X seconds, or similar.

laszlodaniel, 2022-09-27:
This CSV format is a good idea. Wouldn't a single header be enough, though?

```
Timestamp,1412,1415,1416
00:00:29.447,03,11,00
00:00:29.598,03,10,00
00:00:29.735,05,11,00
```

Also which time format is preferable? First I used integer milliseconds while developing the logging feature, then moved on to this "hours:minutes:seconds.milliseconds" format.

dino2gnt, 2022-09-27:
>Wouldn't a single header be enough, though?

Personal preference.  Having the header in multiple places or at an interval is helpful when dealing with long-running CSV.

>Also which time format is preferable?

Dealer's choice :)  I have no opinions on format beyond epoch time being strictly numerical and thus simpler to parse and math on.

laszlodaniel, 2022-09-28:
```
pcmlog_20220928_115214.csv

Milliseconds,1405,1406,1407,1408,1409,140A,140B,140C
542682,174,255,255,64,0,191,234,45
542882,174,255,255,64,0,191,234,45
543083,174,255,255,64,0,191,234,45
543284,174,255,255,64,0,191,234,45
543484,174,255,255,64,0,191,234,45
543685,174,255,255,64,0,191,234,45
543886,174,255,255,64,0,191,234,45
544087,174,255,255,64,0,191,234,45
544287,174,255,255,64,0,191,234,45
544488,174,255,255,64,0,191,234,45
544689,174,255,255,64,0,191,234,45
544889,174,255,255,64,0,191,234,45
545090,174,255,255,64,0,191,234,45
545291,174,255,255,64,0,191,234,45
545491,174,255,255,64,0,191,234,45
545692,174,255,255,64,0,191,234,45
545893,174,255,255,64,0,191,234,45
546094,174,255,255,64,0,191,234,45
546294,174,255,255,64,0,191,234,45
```

Progress:
The header starts with Milliseconds label, followed by requests in 14XX hexadecimal format. Only 1 header line is used for now.
Then each line starts with milliseconds elapsed as an integer number, then comma separated bytes in decimal format.
New CSV-file is created when header line changes, otherwise lines are appended to the current session, even after stopping.

Let me know if this is good for testing!

dino2gnt, 2022-09-28:
Looks fantastic!  Is there a build I can download to test?

laszlodaniel, 2022-09-28:
Thanks! There are now new GUI and scanner firmware updates available. Check Tools / Update menu.

Closed 2022-10-12.

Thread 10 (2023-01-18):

Suspect this line should assign "2004" as this is what my vehicle is and it's responding with "1994 1/2"

nurbers, 2023-01-18:
https://github.com/laszlodaniel/ChryslerScanner/blob/dc3ddec03143a20d7d1a833325280bcdd2e7f342/GUI/ChryslerScanner/SCIPCM.cs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

nurbers, 2023-01-20:
Nice, correct date now shown.  Didn't realize more complicated than just changing date.  Appreciatively

laszlodaniel, 2023-01-20:
Thanks for testing!
I think "1994 1/2" and "1991-1995" is just a workaround for specific controller(s). Those slots were meant to be 2004 and 2005. A better solution would be not to filter by CumminsSelected switch, but assign 2004 and 2005 by default.

Closed 2023-01-20.

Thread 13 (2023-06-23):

V210 KiCAD Project?

ajayre, 2023-06-23:
Hi, Would you would be willing to add the KiCAD project to github? I am interested in this project for my 2006 Jeep Wrangler. I could create my own KiCAD project from the schematic but it would save me a lot of time to just use yours. Thanks! Andy

laszlodaniel, 2023-06-24:
Hi, no way. Good luck with your project!

ajayre, 2023-06-24:
OK, no problem. I appreciate you making this all open source. The DRB III Emulator I have does not work with the PCI bus even with the "XX TI MAP" ground pin fix, so this is pretty interesting to me. I have the emulator running in a virtual machine so maybe the issue is there. I've forked your project. For future reference are you interested in pull requests or do you prefer to work alone on this project?

laszlodaniel, 2023-06-24:
VirtualBox pulled the same behavior on me. The USB comm was not properly routed between host OS (Win 10) and guest OS (Win 7). In the host OS a single Linux USB driver needs to be auto-installed and nothing else. And make sure to follow Emulator installation instructions in the guest OS to the T. I'll get back to you with my setup on Monday.

There are other nuances you should be aware of, while using the Micropod and Emulator. It needs to talk to the PCM on SCI-bus first, to identify the controller, then it moves on to PCI-bus. So if you work on the bench this can make things difficult.
For me the Emulator failed frequently when I bench-tested PCI-bus with a SKIM unit.

For now I want to work on this repository alone, since it's very old and much of the code needs to be cleaned up. Suggestions and protocols are welcome! Although I use the Micropod to extract diagnostic procedures, ever so slowly.

ajayre, 2023-06-24:
I can access the PCM (presumably via SCI) and I can scan for modules and it finds them, but even though the scan finds the MIC for example I cannot access it. And because all of this is a black box there are no debugging options. Your solution looks much better.

Closed 2023-06-24.

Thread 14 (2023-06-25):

Bootstrap/Programming

ajayre, 2023-06-25:
Am I right in understanding that the bootstrap/programming only relates to the SBEC and not JTEC, JTEC+ or NGC?
Thanks, Andy

laszlodaniel, 2023-06-26:
No, the method of bootstrapping applied here is valid for all of those and EATX3 as well. They are all wired to sense high voltages (12V/20V) on their SCI-RX pin. Programming was tested on SBEC/EATX/JTEC units. Protocol for NGC is different and not tested yet.

laszlodaniel, 2023-06-28:
No public documentation is available since I got into this game. It's reverse engineering all the way!
You will find this NGC reflashing log most interesting: [05143318AA_DCX2534.txt](https://github.com/laszlodaniel/ChryslerScanner/files/11891755/05143318AA_DCX2534.txt)
Same protocol applies to NGC1-3 (PCI/SCI-bus).
Please open a new [Discussion](https://github.com/laszlodaniel/ChryslerScanner/discussions) if you have further questions!

Closed 2023-06-28.

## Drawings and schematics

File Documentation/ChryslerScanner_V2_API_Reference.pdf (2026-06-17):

# Chrysler Scanner V2 API Reference

Last Updated: June 5, 2026

## 1. Overview

The Chrysler Scanner firmware acts as a high-speed bridge between modern host applications (Windows, macOS, Android, iOS) and legacy Chrysler automotive networks (CCD, PCI, and SCI).

Communication with the scanner is purely asynchronous, packet-based, and identical across both USB and Bluetooth LE (BLE) transport layers. The scanner operates in a Master/Slave relationship with the host application: the host issues requests or commands, and the scanner responds. The scanner will also independently push asynchronous events (like incoming automotive bus messages) to the host.

## 2. Transport Layers

### 2.1 USB (Serial Port)

Baud Rate: | 250000 | bps (Default, configurable via API)
Data Bits: 8
Parity: None
Stop Bits: 1
Flow Control: None

### 2.2 Bluetooth Low Energy (BLE)

The scanner implements the standard Nordic UART Service (NUS) to emulate a serial stream over BLE.

Service UUID: | 6E400001-B5A3-F393-E0A9-E50E24DCCA9E
RX Characteristic (Host -> Scanner): | 6E400002-B5A3-F393-E0A9-E50E24DCCA9E | (Write /
Write Without Response)
TX Characteristic (Scanner -> Host): | 6E400003-B5A3-F393-E0A9-E50E24DCCA9E | (Notify)

## 3. Packet Framing Protocol

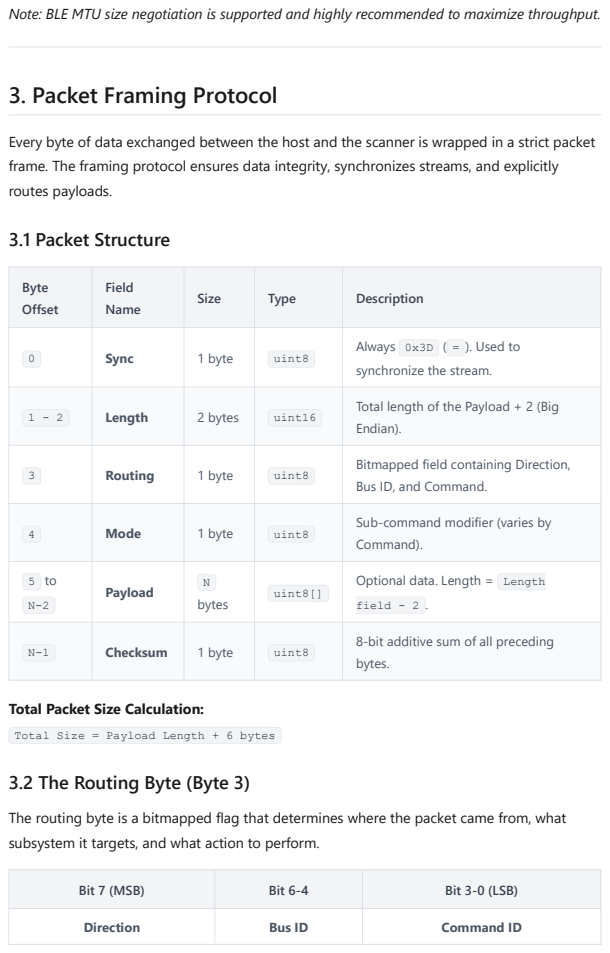
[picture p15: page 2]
3.1 Packet Structure

Note: BLE MTU size negotiation is supported and highly recommended to maximize throughput.

Every byte of data exchanged between the host and the scanner is wrapped in a strict packet
frame. The framing protocol ensures data integrity, synchronizes streams, and explicitly
routes payloads.

Byte Offset | Field Name | Size | Type | Description

0 | Sync | 1 byte | uint8 | Always 0x3D ( = ). Used to synchronize the stream.

1 - 2 | Length | 2 bytes | uint16 | Total length of the Payload + 2 (Big Endian).

3 | Routing | 1 byte | uint8 | Bitmapped field containing Direction, Bus ID, and Command.

4 | Mode | 1 byte | uint8 | Sub-command modifier (varies by Command).

5 to N-2 | Payload Checksum | N bytes 1 byte | uint8[] uint8 | Optional data. Length = Length field - 2 . N-1

8-bit additive sum of all preceding bytes.

Total Packet Size Calculation:

Total Size = Payload Length + 6 bytes
3.2 The Routing Byte (Byte 3)

The routing byte is a bitmapped flag that determines where the packet came from, what
subsystem it targets, and what action to perform.

Bit 7 (MSB) | Bit 6-4 | Bit 3-0 (LSB)

Direction | Bus ID | Command ID

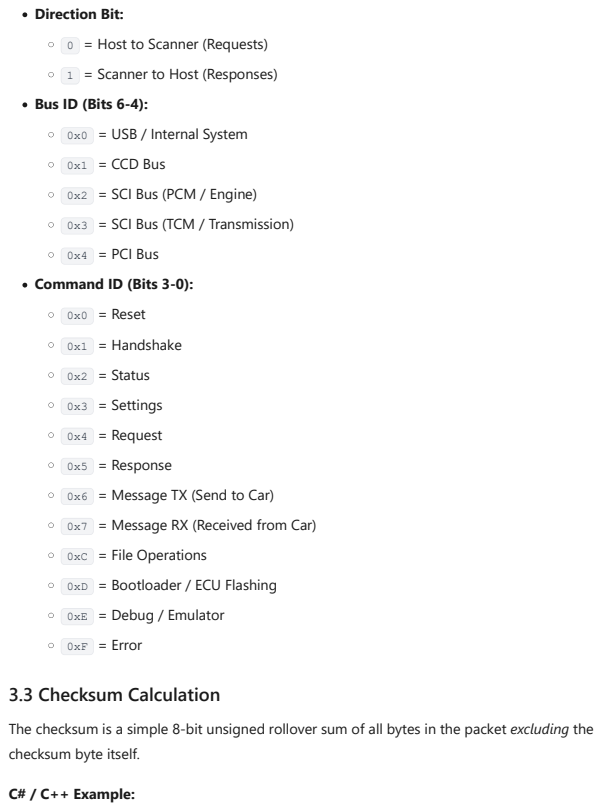
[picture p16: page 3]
= USB / Internal System; = CCD Bus; = SCI Bus (PCM / Engine); = SCI Bus (TCM / Transmission); = PCI Bus; = Reset; = Handshake; = Status; = Settings; = Request; = Response; = Message TX (Send to Car); = Message RX (Received from Car); = File Operations; = Bootloader / ECU Flashing; = Debug / Emulator; = Error; 3.3 Checksum Calculation; C# / C++ Example:

Direction Bit:
0 = Host to Scanner (Requests)
1 = Scanner to Host (Responses)
Bus ID (Bits 6-4):
Command ID (Bits 3-0):

The checksum is a simple 8-bit unsigned rollover sum of all bytes in the packet excluding the
checksum byte itself.

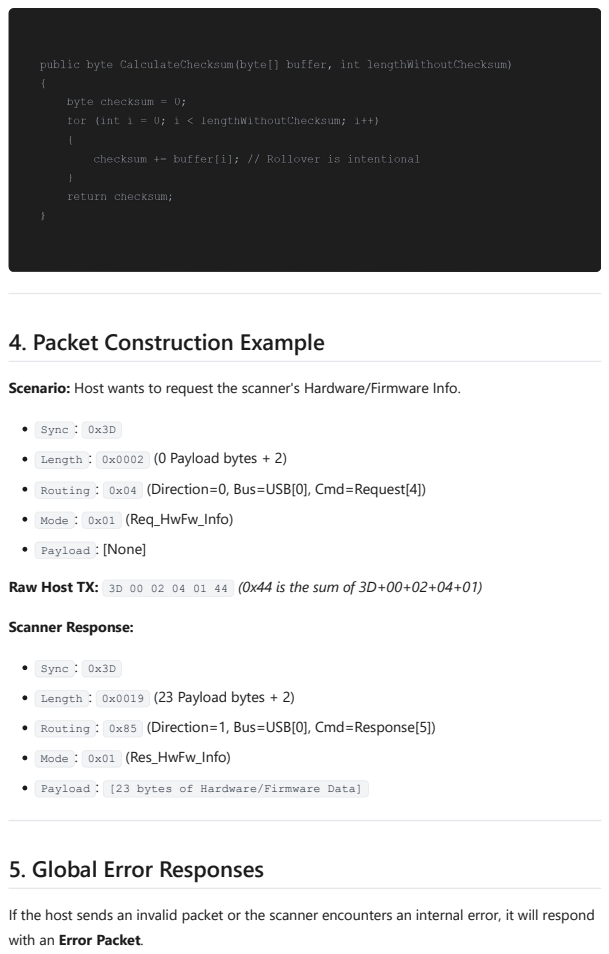
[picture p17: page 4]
Sync; Length; (0 Payload bytes + 2); Routing; (Direction=0, Bus=USB[0], Cmd=Request[4]); Mode; (Req_HwFw_Info); Payload; : [None]; Raw Host TX:; (0x44 is the sum of 3D+00+02+04+01); Scanner Response:; (23 Payload bytes + 2); (Direction=1, Bus=USB[0], Cmd=Response[5]); (Res_HwFw_Info); [23 bytes of Hardware/Firmware Data]

public byte CalculateChecksum(byte[] buffer, int lengthWithoutChecksum)
byte checksum = 0;
for (int i = 0; i < lengthWithoutChecksum; i++)
checksum += buffer[i]; // Rollover is intentional
return checksum;

4. Packet Construction Example

Scenario: Host wants to request the scanner's Hardware/Firmware Info.

5. Global Error Responses

If the host sends an invalid packet or the scanner encounters an internal error, it will respond
with an Error Packet.

Routing Byte: | 0x8F | (Scanner to Host, USB Bus, Error Command) Payload: Usually a single
0xFF | byte, though it can be ignored. Mode Byte (The Error Code):
0x00 | = OK (Acknowledge)
0x01 | = Length Invalid Value
0x02 | = Invalid Command (Command ID not recognized)
0x03 | = Invalid Mode (Mode/Sub-command not recognized)
0x04 | = Invalid Payload Values
0x05 | = Checksum Invalid
0x06 | = Packet Timeout (RX stream stalled)
0x07 | = Buffer Overflow
0x08 | = Invalid Bus
0xFE | = Internal Execution Error
0xFF | = Fatal Error

Example of a standard "OK" ACK from the scanner (Length=3, Payload=[0x00]):

3D 00 03 8F 00 00 CF
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

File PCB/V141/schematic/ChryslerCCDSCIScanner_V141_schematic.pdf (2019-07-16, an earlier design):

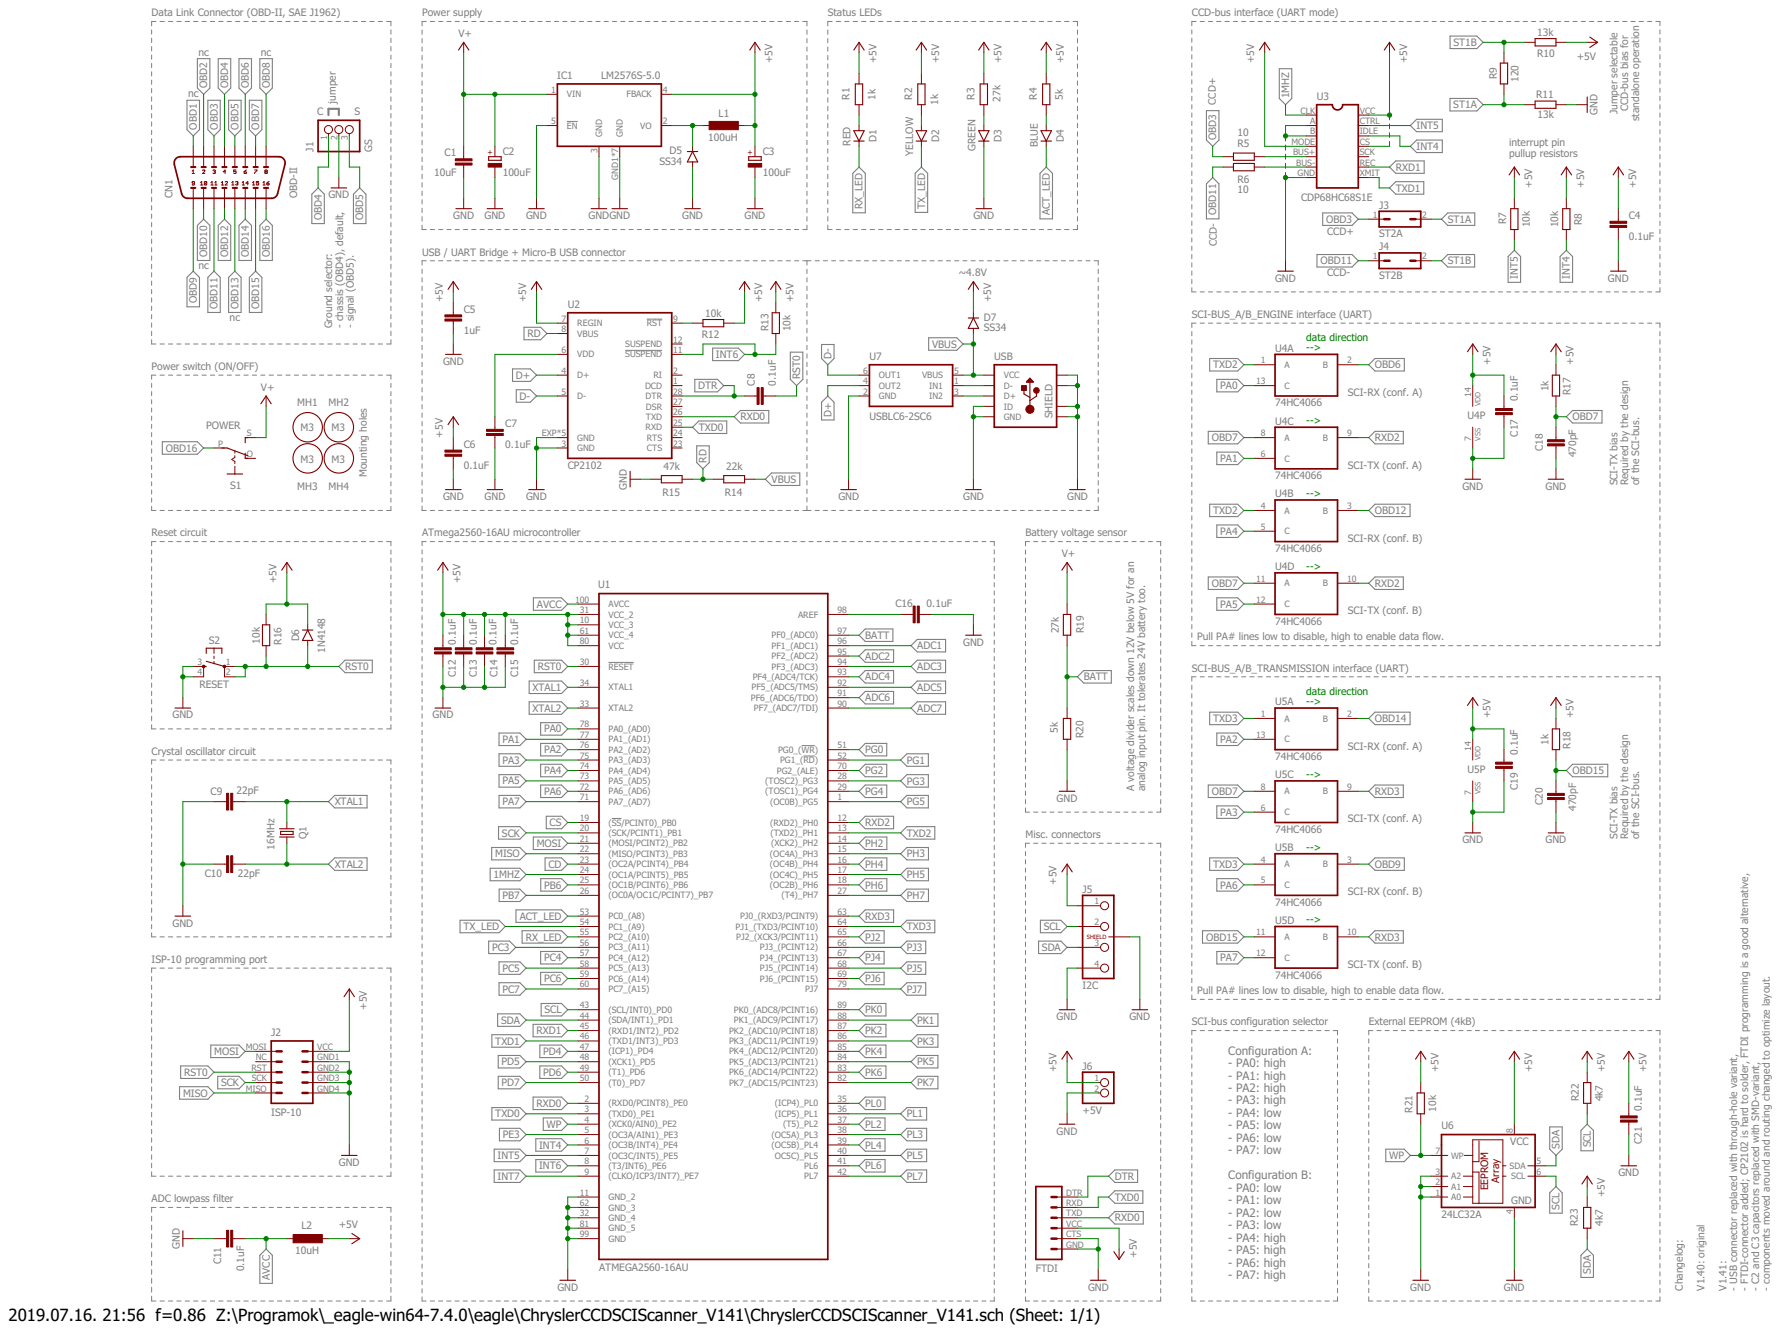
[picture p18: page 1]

Jumper selectable CCD-bus bias for standalone operation

OBD-II GS GND

SCI-BUS_A/B_ENGINE interface (UART) Ground selector: - chassis (OBD4), default, - signal (OBD5).

USB / UART Bridge + Micro-B USB connector

Power switch (ON/OFF)

SCI-TX bias Required by the design

of the SCI-bus.

A voltage divider scales down 12V below 5V for an

analog input pin. It tolerates 24V battery too. SCI-bus configuration selector

Pull PA# lines low to disable, high to enable data flow.

Changelog: V1.40: original V1.41: - USB connector replaced with through-hole variant, - FTDI-connector added; CP2102 is hard to solder, FTDI programming is a good alternative, - C2 and C3 capacitors replaced with SMD-variant, - components moved around and routing changed to optimize layout.

Pull PA# lines low to disable, high to enable data flow. External EEPROM (4kB)

44 SDA | PK1

45 RXD1 | PK2

TXD1 | PK3

2019.07.16. 21:56 f=0.86 Z:\Programok\_eagle-win64-7.4.0\eagle\ChryslerCCDSCIScanner_V141\ChryslerCCDSCIScanner_V141.sch (Sheet: 1/1)

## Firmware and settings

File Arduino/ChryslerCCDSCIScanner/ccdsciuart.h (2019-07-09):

/*
 * ChryslerCCDSCIScanner (https://github.com/laszlodaniel/ChryslerCCDSCIScanner)
 * Copyright (C) 2018-2019, László Dániel
 *
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
 * UART code is based on original library by Andy Gock:
 * https://github.com/andygock/avr-uart
 */

#ifndef CCDSCIUART_H
#define CCDSCIUART_H

#define FW_DATE 0x000000005D248686  // Firmware date/time of compilation in 64-bit UNIX time

// RAM buffer sizes for different UART-channels
#define USB_RX0_BUFFER_SIZE 1024
#define CCD_RX1_BUFFER_SIZE 64
#define PCM_RX2_BUFFER_SIZE 64
#define TCM_RX3_BUFFER_SIZE 64

#define USB_TX0_BUFFER_SIZE 1024
#define CCD_TX1_BUFFER_SIZE 64
#define PCM_TX2_BUFFER_SIZE 64
#define TCM_TX3_BUFFER_SIZE 64

#define USB_RX0_BUFFER_MASK (USB_RX0_BUFFER_SIZE - 1)
#define CCD_RX1_BUFFER_MASK (CCD_RX1_BUFFER_SIZE - 1)
#define PCM_RX2_BUFFER_MASK (PCM_RX2_BUFFER_SIZE - 1)
#define TCM_RX3_BUFFER_MASK (TCM_RX3_BUFFER_SIZE - 1)

#define USB_TX0_BUFFER_MASK (USB_TX0_BUFFER_SIZE - 1)
#define CCD_TX1_BUFFER_MASK (CCD_TX1_BUFFER_SIZE - 1)
#define PCM_TX2_BUFFER_MASK (PCM_TX2_BUFFER_SIZE - 1)
#define TCM_TX3_BUFFER_MASK (TCM_TX3_BUFFER_SIZE - 1)

// ATmega2560-specific UART registers and vectors
// USB: UART0
// CCD: UART1
// PCM: UART2
// TCM: UART3

#define USB_RECEIVE_INTERRUPT   USART0_RX_vect
#define CCD_RECEIVE_INTERRUPT   USART1_RX_vect
#define PCM_RECEIVE_INTERRUPT   USART2_RX_vect
#define TCM_RECEIVE_INTERRUPT   USART3_RX_vect
#define USB_TRANSMIT_INTERRUPT  USART0_UDRE_vect
#define CCD_TRANSMIT_INTERRUPT  USART1_UDRE_vect
#define PCM_TRANSMIT_INTERRUPT  USART2_UDRE_vect
#define TCM_TRANSMIT_INTERRUPT  USART3_UDRE_vect
#define USB_STATUS              UCSR0A
#define USB_CONTROL             UCSR0B
#define USB_DATA                UDR0
#define USB_UDRIE               UDRIE0
#define CCD_STATUS              UCSR1A
#define CCD_CONTROL             UCSR1B
#define CCD_DATA                UDR1
#define CCD_UDRIE               UDRIE1  
#define PCM_STATUS              UCSR2A
#define PCM_CONTROL             UCSR2B
#define PCM_DATA                UDR2
#define PCM_UDRIE               UDRIE2  
#define TCM_STATUS              UCSR3A
#define TCM_CONTROL             UCSR3B
#define TCM_DATA                UDR3
#define TCM_UDRIE               UDRIE3

// Bit-flags in the high byte of the receive buffer
#define CCD_SOM                 0x8000  /**< Start of message on CCD-bus    10000000 00000000 - ARBITRARY */
#define PCM_SOM                 0x4000  /**< Start of message on SCI-bus    01000000 00000000 - ARBITRARY */
#define TCM_SOM                 0x2000  /**< Start of message on SCI-bus    00100000 00000000 - ARBITRARY */
#define UART_FRAME_ERROR        0x1000  /**< Framing Error by UART          00010000 00000000 - FIXED BIT */ 
#define UART_OVERRUN_ERROR      0x0800  /**< Overrun condition by UART      00001000 00000000 - FIXED BIT */
#define UART_BUFFER_OVERFLOW    0x0400  /**< Receive ringbuffer overflow    00000100 00000000 - ARBITRARY */
#define UART_RX_NO_DATA         0x0200  /**< Receive buffer is empty        00000010 00000000 - ARBITRARY */
//                                                                          FLAGS    DATA

// Fixed bytes
//#define CCD_DIAG_REQ    0xB2  // Diagnostic request ID-byte for CCD-bus
//#define CCD_DIAG_RESP   0xF2  // Diagnostic response ID-byte for CCD-bus
//#define SCI_FAULT_CODES 0x10  // Command to request fault codes on SCI-bus
//#define SCI_HI_SPEED    0x12  // Command to switch SCI-bus to high speed mode (62500 baud)
//#define SCI_LO_SPEED    0xFE  // Command to switch SCI-bus to low speed mode (7812.5 baud)

// Baudrate prescaler calculation: UBRR = (F_CPU / (16 * BAUDRATE)) - 1
#define LOBAUD  127  // prescaler for 7812.5 baud speed (CCD-SCI / default low-speed diagnostic mode)
#define HIBAUD  15   // prescaler for  62500 baud speed (SCI / high-speed parameter mode)
#define USBBAUD 3    // prescaler for 250000 baud speed (USB)

#define INT4          2  // CCD-bus idle interrupt pin
#define INT5          3  // CCD-bus active byte interrupt pin
#define CCD_CLOCK_PIN 11 // clock generator output for CCD-bus
#define RX_LED        35 // status LED, message received
#define TX_LED        36 // status LED, message sent
#define ACT_LED       37 // status LED, activity
#define BATT          A0 // battery voltage sensor

#define SCI_INTERFRAME_RESPONSE_DELAY   100  // milliseconds elapsed after last received byte to consider the SCI-bus idling
#define SCI_INTERMESSAGE_RESPONSE_DELAY 50   // ms
#define SCI_INTERMESSAGE_REQUEST_DELAY  50   // ms

#define PA0 22 // SCI-bus configuration selector digital pins on ATmega2560
#define PA1 23 // |
#define PA2 24 // |
#define PA3 25 // |
#define PA4 26 // |
#define PA5 27 // |
#define PA6 28 // |
#define PA7 29 // |

#define STOP  0x00
#define START 0x01

// Packet related stuff
#define PACKET_SYNC_BYTE    0x3D // = symbol
#define ASCII_SYNC_BYTE     0x3E // > symbol
#define MAX_PAYLOAD_LENGTH  USB_RX0_BUFFER_SIZE - 6  // 1024-6 bytes
#define EMPTY_PAYLOAD       0xFE  // Random byte, could be anything

#define TEMP_BUFFER_SIZE    32

// DATA CODE byte building blocks
// Source and Target masks (high nibble (2+2 bits))
#define from_usb            0x00 // when sending packets back to laptop use "from_" masks to specify source
#define from_ccd            0x01
#define from_pcm            0x02
#define from_tcm            0x03
#define to_usb              0x00 // when receiving packets from laptop use "to_" masks as target, "to_usb" meaning the scanner itself
#define to_ccd              0x01
#define to_pcm              0x02
#define to_tcm              0x03
// Commands (low nibble (4 bits))
#define reset               0x00
#define handshake           0x01
#define status              0x02
#define settings            0x03
#define request             0x04
#define response            0x05
#define msg_tx              0x06
#define msg_rx              0x07
// 0x08-0x0D reserved
#define debug               0x0E
#define ok_error            0x0F

// SUB-DATA CODE byte
// Command 0x00 (reset)
// 0x00-0xFF reserved

// SUB-DATA CODE byte
// Command 0x01 (handshake)
// 0x00-0xFF reserved

// SUB-DATA CODE byte
// Command 0x02 (status)
// 0x00-0xFF reserved

// SUB-DATA CODE byte
// Command 0x03 (settings)
#define heartbeat           0x00 // ACT_LED flashing interval is stored in payload
#define set_ccd_bus         0x01 // ON-OFF state is stored in payload
#define set_sci_bus         0x02 // ON-OFF state, A/B configuration and speed are stored in payload
// 0x03-0xFF reserved 

// SUB-DATA CODE byte
// Command 0x04 & 0x05 (request and response)
#define hwfw_info           0x00 // Hardware version/date and firmware date in this particular order (dates are in 64-bit UNIX time format)
#define timestamp           0x01 // elapsed milliseconds since system start
#define battery_voltage     0x02 // as the name says
#define exteeprom_checksum  0x03
// 0x02-0xFF reserved
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

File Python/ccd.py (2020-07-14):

import serial
import time
import argparse


com = serial.Serial()
# com.port = 'COM3'
com.port = '/dev/ttyUSB0'
com.baudrate = 250000
com.timeout = 2
com.dtr = None  # Disable auto-reset upon USB-connection
com.open()


def send_requests():
    time.sleep(4)  # wait for reset
    with open('requests.txt', "r") as f:
        for line in f:
            request = bytes.fromhex(line.replace('\n', ''))
            packet_length = 2 + len(request)
            packet_length_hb = (packet_length >> 8) & 0xFF
            packet_length_lb = packet_length & 0xFF
            packet = bytearray([0x3D, packet_length_hb, packet_length_lb, 0x16, 0x02])
            packet.extend(request)

            checksum = 0
            i = 1
            while i < len(packet):
                checksum += packet[i]
                i += 1

            checksum = (checksum & 0xFF).to_bytes(1, 'little')
            packet.extend(checksum)

            com.write(packet)

            echo = False
            timeout = time.time() + 2
            while not echo:
                if time.time() > timeout:
                    break
                if com.inWaiting():
                    data = None
                    try:
                        data = com.read(com.inWaiting())
                    except TypeError:
                        pass
                    if len(data) > 9:
                        if data[9] == 0xF2:
                            echo = True
                            response = data[9:(len(data)-1)]
                            print(" ".join(["{:02x}".format(x) for x in request]).upper())
                            print(" ".join(["{:02x}".format(x) for x in response]).upper())
                            with open('codes.txt', "a") as codes:
                                codes.write(" ".join(["{:02x}".format(x) for x in request]).upper() + "\n")
                                codes.write(" ".join(["{:02x}".format(x) for x in response]).upper() + "\n\n")
            if not echo:
                print(" ".join(["{:02x}".format(x) for x in request]).upper() + ": timeout")
    com.close()


def read_ccd_bus():
    while True:
        if com.inWaiting():
            data = None
            try:
                data = com.read(com.inWaiting())
            except TypeError:
                pass
            if data[3] == 0x47 and len(data) > 9:
                message = data[9:(len(data)-1)]
                print(" ".join(["{:02x}".format(x) for x in message]).upper())
                with open('messages.txt', "a") as messages:
                    messages.write(" ".join(["{:02x}".format(x) for x in message]).upper() + "\n")
    com.close()


parser = argparse.ArgumentParser(description='CCD-bus reader script')
parser.add_argument('operation')
args = vars(parser.parse_args())

if args['operation'] == 'write':
    send_requests()

if args['operation'] == 'read':
    read_ccd_bus()

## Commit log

2018-07-31 Maximum payload length and ringbuffer byte-order changed
    Maximum payload length changed to 1k (-6 bytes) although the microcontroller could handle more. Receive ringbuffers had high/low-byte order reversed. Flags should be in the high byte and data in the low byte. LED-states were also reversed: they light up when grounded.
    [ccdsciuart.h]
2020-01-13 Latest PCB update
    [ChryslerCCDSCIScanner_V143.drills.xln]
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2020-02-08 Update
    So much got updated. First in the Arduino code I grouped all the bus-related variables into structures. Handshake bytes are moved to RAM instead of program memory. Then I added an experimental PCM me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
2020-02-12 Update
    Added new CCD-bus message descriptions (35, B1, F1).
    Added metric conversion to the 7B-message (outside temperature, CCD-bus).
2020-02-12 Update
    Improved repeated message behavior settings that is now selectable for each bus. Arduino code a bit simplified when handling "out of range" packets.
2020-02-14 Update
    "Reset View" button behavior fixed by uncommenting an important method call.
2020-02-20 Update
    In Arduino code there are two helper defines that convert raw bytes to word (uint16) and double-word (uint32).
    GUI About form modified to always appear in the center of the main form.
    Expanding/collapsing the main form keeps it in the same place.
2020-02-20 Update
    Expand/collapse button behavior restored. It was a bad idea to turn off screen centering.
2020-02-22 Update
    Diagnostics table is updated periodically instead of every time when a new message arrives. Heavy CCD-bus activity can slow down the table update and eventually causing delay. Default refresh rate is 50 milliseconds and it can be changed under the table.
    Table blinking is reduced by removing the "update" and "refresh" methods when the table is changed.
    Fixed a bug where the ID-bytes of PCM/TCM messages were not saved and therefore not evaluated.
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2020-07-23 Legacy OBD1 SCI-bus support for the custom engine cable (CHRY-6)
    SCI-bus communication now complies with legacy standards described here:
    https://pcm.neons.org/doku.php?id=sci_tech_info
    When the OBD1 SCI engine cable is used to communicate with the engine controller select "Settings / OBD1 SCI engine cable used" and send a "Set SCI-bus" settings packet to apply it in the scanner too.
    Furthermore, new CCD-bus message interpretations were added.
    Also when a B2 request message is echoed on the CCD-bus the previous F2 response message is automatically removed as to not confuse it with the current request.
2020-07-25 Fixed arbitrary UART-speed selector in GUI
2020-09-01 Major update.
    [ChryslerCCDSCIScanner_V144.drills.xln]
2020-09-09 LCD update
    LCD I2C address is now configurable and defaults to 0x27, which is a common address.
2020-09-14 Fix SCI-bus low speed parameter scaling on LCD.
    Variables for CCD-bus voltage measurements renamed for clarity.
2020-09-21 Fix SCI-bus low-speed mode fuel level scaling and cruise set switch state
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2020-11-26 Enable UART3-channel (TCM)
    Rudimentary UART3-channel functionality restored. GUI updated to show TCM diagnostic table.
    PCM and TCM module on SCI-bus tab now selectable. Transmitted messages are directed to the selected module.
    Diagnostic table snapshot button restored, timestamped textfile is saved in the appropriate log folder.
2020-12-07 Fix CCD-bus data display delay
    Diagnostic listbox update is buffered and limited to update every 25 milliseconds only. The GUI remains responsive during overwhelming data transfer.
    CCD-bus transceiver is turned off by default. Added new setting for on-demand CCD-bus data display. When enabled CCD-bus data is processed only if the control panel has the CCD-bus tab selected.
2020-12-08 Fix SCI-bus setting broadcast on startup
    SCI-bus settings packet was sent at startup before UART-channels were initialized causing all sorts of issues.
2020-12-08 Update C23 and C24 value in V1.44 PCB
    These two capacitors smooth CCD-bus signals. The earlier 100 nF capacitance causes large signal rise/fall-time delay. Signal levels become stable right before half-bit times when samples are taken. O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
2020-12-08 Improve connection sequence to the scanner
    Timeout flag was set after first initializing the timeout timer. Enabling the timer also starts it and sets the flag eventually. Consequently the first connection attempt timeouts immediately and onl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
    Now timer is stopped after initialization and flags are cleared at various steps for good measure.
2020-12-09 Improve diagnostic table refresh method
    When a diagnostic table content changes then the new/modified line is first stored in a buffer. This buffer is read by individual timers, on the main thread set to 25 ms, and update tables accordingl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
2020-12-24 Major code refactoring
    Arduino code got a big overhaul. Modules are separated.
    Fixes #3 and #4.
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2021-02-26 Implement module memory reader over CCD/SCI-bus
    An experimental version of the long awaited modul memory/firmware/binary reader is here under the "Tools / Read memory" menu.
    Tested with a Body Control Module (BCM) over CCD-bus (64 kB) and a Powertrain Control Module (PCM) over SCI-bus (128 kB).
    Reading speed is quite slow (1-2 hour / 64 kB), further improvements are to be expected.
    Reading sessions can be suspended and resumed provided the popup window is not closed. Multiple timeout measures are in place to ensure data integrity and to avoid hiccups.
    Further help is displayed via the Help button and a new blog post is under drafting.
2021-06-13 Remove Gerber files
    [ChryslerCCDSCIScanner_V140.drills.xln, ChryslerCCDSCIScanner_V141.drills.xln, ChryslerCCDSCIScanner_V142.drills.xln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]
2021-06-21 Fix high-speed mode malfunction and low-speed mode actuator tests
    Due to the improper use of the sizeof() function on arrays the scanner behaved weirdly. All known array lengths are typed out explicitly.
    The weird behavior of the actuator tests are fixed by transmitting the test byte back to the laptop every 200 ms, instead of the way too fast ~20 ms dictated by the PCM. This way the GUI remains responsive and stopping an actuator test becomes more efficient.
2021-06-22 Improve elapsed time comparison
    Time differences are casted to uint32_t type to prevent negative results when the millis() function overflows after 49.7 days.
    Every millis() measurements are saved in the global current_millis variable.
2021-07-05 Fix SCI-bus table update error, add cam/crank sensor state definition to SCI-bus high-speed mode
    SCI-bus table update routine was faulty when the scanner started up at 62500 baud.
    RAM-tables kept repeating instead of overwriting each other and new lines were added in the main table even though they contained the same ID-byte.
    SCI-bus high-speed mode parameter F4 41 is now interpreted (crank/cam sensor state).
    Add experimental form for memory writing. Its menu is disabled for now.
2021-07-15 Fix CCD-bus ID 54 interpretation, improve SCI-bus security seed feature
    It turns out that CCD-bus message ID 54 contains the MAP-sensor value and the engine coolant temperature. The MAP-sensor was mistaken for transmission temperature.
2021-07-15 Add A/C clutch relay state CCD-bus message (7E), improve CCD-bus ID 50 interpretation
2021-07-15 Fix CCD-bus ID 54 interpretation
    This message seem to contain the barometric pressure and another kind of temperature after all, most likely ambient/battery temperature.
2021-07-16 Fix CCD-bus IDs 02 52 7E, add transmission temperature request/response interpretation
2021-08-18 Update CCDLibrary to v0.8.2
    CCD-bus arbitration detector is temporarily disabled for custom transceiver circuits.
2021-09-12 Fix voltage and mileage scaling
2021-09-13 Fix SCI ID 2A request handler, fix voltage and distance scaling on LCD
2021-09-19 Fix PCM actuator tests on SCI-bus
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2022-03-18 Implement PCM EEPROM restore feature
    Under the Tools / Write memory menu the "RES" button restores EEPROM values from a backup binary file.
    First it reads the current memory value and writes a new value only if it's different.
    All requests and responses are handled by the scanner. The code is blocking by nature, so unlike with other read/write tasks the scanner and GUI becomes unresponsive until the task is done (~45 seconds) or an error occurs.
2022-03-29 Add SBEC3 part number reader worker function
    Worker functions are not started automatically after upload. The GUI has a "Start" button in the Bootstrap tools form.
2022-03-30 Change delay in Flash ID worker function
    Delay shortened from 20 ms to 10 ms. Should be enough time to apply bootstrap(or programming) voltage when needed.
2022-05-05 Fix SCI-bus RAM value request bug
    SCI-bus responses were incorrectly assembled after sending a list of request messages to SCI-bus at high-speed mode.
    This bug lurked there since bootstrap support was added.
2022-06-15 Improve SCI-bus actuator test mode
    During an actuator test the test mode value is no longer streamed by the PCM. This enables parallel working: while an actuator test is running the user can request other diagnostic data.
    Added SCI-bus NGC mode handler. In this mode messages are sent in bursts, without checking echo. Further improvements are necessary.
2022-06-22 Add SBEC3 re-programming tools and engine tools
    The "Tools / Bootstrap tools" menu now features a complete SBEC3 re-programming solution. It makes backups of the current flash memory and EEPROM content. Supports common 128k and 256k flash memories.
    The "Tools / Engine tools" menu features important tools to aid navigation in the multitude of SCI-bus PIDs. Applies to SBEC2/SBEC3/JTEC units. To be expanded.
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2022-06-27 Add PlatformIO project for v2 hardware
    [esp_efuse_custom_table.csv, esp_efuse_table.csv, partition_custom_table.csv]
2022-07-05 Fix PCI-bus idle handler
    Start of frame (SOF) flag was not cleared after receiving a message, causing subsequent message drops.
2022-07-06 Improve part number analyzer
    Earlier part numbers don't have a double letter appended as revision indicator (AA, AB...), instead 99 is used.
    Add SCI ID 14 PIDs for intake air temperature, fuel system status, Cam/Crank sync status.
2022-08-18 Fix value comparison evaluation
    Use "greater or equal" condition instead of "equal" in case of PulseCount overruns for some reason.
2022-08-23 Fix value comparison evaluation
    Use "greater or equal" condition instead of "equal" in case of Attampts overruns for some reason.
2022-10-21 Fix oxygen sensor voltage/level confusion
2022-10-26 Fix sensor voltage scaling accuracy
2022-11-13 Add Teves/ATE ABS MK4-G and MK20 features
    Features implemented:
    - read ABS ID,
    - read fault codes,
    - erase fault codes.
    Future features:
    - read wheel speeds,
    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
2022-11-15 Fix PCI EA transmission temperature scaling
2022-11-15 Various hotfixes
    Add transmission fan relay state to CCD/PCI message handlers.
    Add SCI 13 45, 13 47, 13 50, 13 51 actuator test mode descriptions.
    Add SCI F4 61 message description.
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2022-12-16 Fix cruise and temperature message scaling
    PCI 1A message has set cruise speed in raw km/h units. Ambient temperature offset is only 40 units (same as in PCI C0 message).
2022-12-16 Fix PCI CC outside air temperature scaling
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2023-04-06 Improve SCI-bus logic settings
    It is now possible to select 4 different SCI-bus logic:
    - inverted logic + 4-bit switch around: OBD1 SBEC
    - inverted logic: OBD1 JTEC
    - non-inverted logic: OBD2
    - non-inverted logic w/ SCI-II: OBD2 NGC
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2023-12-07 Change codebase
    [esp_efuse_custom_table.csv, esp_efuse_table.csv, partition_custom_table.csv]
2024-05-24 OBD1 backward compatibility for V2.1.0 scanners
    V2.1.0 scanners were sold with external SCI-bus logic inverter built into adapter cables.
    V2.2.0 scanners deal with inverted SCI-bus logic internally and use simpler adapter cables.
    GUI bootstrap feature now ignores CCD/PCI-bus messages when scanner is used in-vehicle. PCM might be down but other modules still talk over these buses.
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2024-07-26 Fix TPS value on LCD screen
    Throttle pedal pressed percentage has been replaced with sensor voltage difference.
2024-08-26 Improve bus transceiver behavior
    So far bus interrupts were firing regardless of on/off state. This may have interfered with SCI-bus operations while flashing a controller in-vehicle.
    Now bus interrupts are properly disabled.
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

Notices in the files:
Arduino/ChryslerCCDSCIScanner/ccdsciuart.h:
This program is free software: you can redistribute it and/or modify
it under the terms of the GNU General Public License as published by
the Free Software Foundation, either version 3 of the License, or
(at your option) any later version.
